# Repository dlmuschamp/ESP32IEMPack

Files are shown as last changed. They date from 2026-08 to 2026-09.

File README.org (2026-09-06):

* ESP32 Wireless IEM Pack

A first-pass wireless in-ear monitor (IEM) system: one ESP32 transmitter pack
and one ESP32 receiver pack (with support for up to 7 receiver packs).

- *RX path:* ESP-NOW -> ESP32 -> I2S -> PCM5102 DAC -> dual-gang volume pot ->
  MAX97220A headphone amp -> 3.5 mm jack
- *TX path:* TRS line-in -> PCM1808 ADC -> ESP32 I2S -> ESP-NOW to paired RX

*v1.0 boards are routed and quoted for fab* (JLCPCB Gerbers / BOM / CPL under
each =jlcpcb/production_files/=). Silk / cosmetic artwork may still change;
electrical intent for this spin is frozen. There is *no display on this version*
(a screen is a later idea, not this revision).

** First project --- how this happened

This is my first self-guided embedded systems project. Before late July 2026 I
had not written C for firmware, had not used ESP-IDF / FreeRTOS, had not read
audio or RF datasheets for a real build, and had never opened KiCad or laid out
a PCB. Pretty much everything that led to these boards was learned on the spot.

I started on a *breadboard with breakout boards* --- ESP32 modules, PCM5102,
amp, mess of jumpers --- without knowing if any of it would work. After a lot
of trial and error (wrong I2S slot formats, muted DAC, power noise, ESP-NOW
quirks), the breadboard path played audio. That proof is what made transferring
the design into KiCad worth doing.

The notes and "common mistakes" section below are the scars from that process.

Capacitor *types* to buy (ceramic vs polarized) by schematic location:
=docs/capacitor_bom.org=. PCM5102 on the RX is *PLL mode* (=SCK= to GND) with
I2S data from the ESP --- see that file.

** Timeline (repo + calendar)

| When | What |
|------+------|
| *2026-07-29* | Repo =init= (GitHub created ~2026-07-30) |
| *~2026-07-31* | Breadboard bring-up in earnest (starter code, then square-wave / DAC path) |
| *2026-08-01* | Working 440 Hz I2S tone; Philips slot fix for unmuted DAC |
| *2026-08-04 -- 08* | RX hierarchical schematics; ERC; RX schematic v1.0.0 |
| *2026-08-15* | TX audio path work (PCM1808 / 32-bit I2S slots) |
| *2026-08-30* | RX PCB layout complete; JLCPCB parts mapped; first production export |
| *2026-08-31* | RX schematics finished for v1; TX schematic draft committed |
| *2026-09-01 -- 02* | TX PCB layout + shared-part LCSC alignment; both boards ready to order |

From first commit to order-ready boards is about *five weeks* (~35 calendar
days: 2026-07-29 -> 2026-09-02). Git history on =main= has *42 commits* across
*16 days with commits*. Clustering those commit timestamps (sessions split when
gaps exceed ~3 h) gives a *lower bound on the order of ~30 hours* of
repo-visible work --- that undercounts dead ends, breadboard evenings without a
commit, and KiCad sessions that never landed in git. Real wall-clock time is
higher.

This ran in parallel with *Arbor Live* ops work at roughly *10--15 hours per
week* (~50--75 hours across the same five weeks). The IEM pack was nights and
leftover bandwidth, not a full-time build.

** Firmware

All application code is *C*. It runs on *FreeRTOS* under *ESP-IDF*, using the
related Espressif libraries (ESP-NOW / Wi-Fi, I2S, ADC, LEDC, NVS). There is
*no hardware abstraction layer* --- the firmware calls ESP-IDF APIs directly.

- =main/tx.c= :: Transmitter. Done for this version (ESP-NOW, ADC pot,
  audio packet path).
- =main/rx.c= :: Receiver entry.  Also mainly done. Use =IEM_NODE=RX= when
  you flash it.
- =main/square_wave_test.c= :: Bench I2S tone used to prove the DAC path.
- =main/rig_shared.h= :: Shared packet and state types for TX and RX.

A packet sniffer / monitor node was an early idea. It is *not* part of this
version. It could come back later as a future extension (=IEM_NODE=MON= is a
leftover hook in =main/CMakeLists.txt=). Do not treat =sniffer.c= as shipping
firmware.

How to flash the firmware onto the TX and RX packs:

#+BEGIN_SRC bash
IEM_NODE=TX idf.py fullclean flash
IEM_NODE=RX idf.py fullclean flash
#+END_SRC

=main/CMakeLists.txt= refuses to build if =IEM_NODE= is missing. That is
intentional so you do not flash the wrong image.

May need to build ESP's libraries in the project root directory first:
#+BEGIN_SRC bash
cd ESP32IEM_Pack
get_idf
#+END_SRC

** Firmware design philosophy

I did not start with a fixed architecture diagram. The philosophy below is what
*emerged* once the breadboard proved audio could move, and once ESP-NOW + I2S
constraints became real. Almost every choice in =main/tx.c=, =main/rx.c=, and
=main/rig_shared.h= is intentional --- latency, robustness, and keeping the
Wi-Fi task thin.

*** Explicit state machines (not a pile of flags)

TX and RX each run a small mode enum driven from =app_main= (=TX_MODE_*= /
=RX_MODE_*=): boot → idle/pairing → transmit/playback, with helpers like
=run_idling_state= / =run_transmitting_state= / =run_audio_playback_state=.

Why: pairing, link loss, and audio streaming are different contracts. A state
machine makes illegal transitions obvious (e.g. do not enqueue audio while still
advertising), keeps =recv_cb= from becoming a second control plane, and matches
how I already think about systems --- events in, one current mode out. Soft
reconnect (audio-sized frames from a known TX while still pairing) is a
*deliberate* exception with a named path (=try_soft_reconnect_from_audio=), not
an accidental fall-through.

*** Packet *size* is the type tag

On the wire there is no separate "opcode" header for the common path. Handlers
branch on =data_size=:

- pairing request ≈ =sizeof(pairing_req_packet_t)= (alias string)
- pairing ACK/NACK = 1 byte (=PAIR_ACK_LEN=; legacy =sizeof(pair_state_t)= also
  accepted on RX)
- audio = =sizeof(audio_packet_t)= (240 interleaved =int16= samples → 480 B)

Why: ESP-NOW already gives you length. Another type byte would cost payload
budget and another branch on every ~2.5 ms audio frame. Distinct struct sizes
make the hot path a few integer compares. Wrong-sized frames are ignored (with
rate-limited logs while pairing so a TX audio flood cannot spam the console at
~400 Hz).

*** Low overhead on the audio path (bitwise / packing / queues of pointers)

Audio is the budget that matters. Design choices that keep CPU and copies down:

- *Pack once.* I2S often delivers 32-bit slot words; TX shifts with =>>= 16= into
  =int16= PCM for the air format (PCM1808 / slot width forced this; the shift is
  the cheap conversion, not a float path).
- *Low-latency packets (this branch).* 240 samples @ 48 kHz = 2.5 ms/packet,
  ~400 pkt/s --- aggressive vs the old 7.5 ms / ~133 pkt/s breadboard-stable
  choice. Relies on =send_cb= pacing + RX pointer-pool. If ESP-NOW drops climb,
  step toward 288 samples (3 ms) before abandoning the ~10 ms e2e target.
- *Pointer-pool jitter buffer on RX.* Queues carry =audio_packet_t *= into a
  fixed pool, not full packet copies on every hop; playback pins to another core
  with a short pre-buffer (2 packets / 5 ms) so the first I2S write does not
  underrun. PCM5102: close =SW2= (FLT=IIR) for ~0.4 ms less DAC filter delay.
- *Keep heavy work off Wi-Fi callbacks.* Pairing work is queued to the state
  machine; =esp_now_add_peer= and I2S enable happen in safe contexts. Send
  pacing waits for =send_cb= so bursts do not disorder callbacks / =NO_MEM=.
- *Silence is zeros, not a skipped send* while transmitting, so the RX timeout
  logic sees a live link instead of a mysterious gap.

None of this was "optimize everything." It was: find the hot path, make the
common case boring and cheap, and put complexity in pairing / reconnect where
milliseconds matter less than correctness.

*** What I refused to do (for v1)

- No HAL wrapping ESP-IDF --- I wanted to learn the real APIs.
- No sniffer/monitor node in the shipping image (hook left in CMake only).
- No display firmware on this revision.
- Unencrypted ESP-NOW for now (explicit TODO, not forgotten security theater).

*** Files to read

- =main/rig_shared.h= --- packet structs, sample counts, ESP-NOW v2 gate
- =main/tx.c= --- TX modes, size-filtered pairing recv, I2S → pack → send
- =main/rx.c= --- RX modes, size-based dispatch, soft join, pointer-pool playback

** What this version is (and is not)

| Topic    | This version (v1.0 order spin)                   | Not this version                         |
|----------+--------------------------------------------------+------------------------------------------|
| Display  | None                                             | A screen or later UI                     |
| RX power | USB-C from a 10,000 mAh 5 V bank -> LM3940 3.3 V | TP4056 + 2000 mAh LiPo/3xAA (Deprecated) |
| TX power | The same kind of 10,000 mAh 5 V bank as the RX   | A different chemistry or one shared bank |
| Radio    | ESP32-WROOM-32U/UE + =ANT1= 2.4 GHz U.FL pigtail | On-module PCB antenna (32E / 32D)        |
| RX audio | I2S -> PCM5102 -> pot -> MAX97220A -> jack       | I2C audio (DAC/ADC here are I2S)         |
| TX audio | TRS -> PCM1808 ADC -> I2S -> ESP-NOW             | Shared ADC/DAC IC across TX and RX       |
| Firmware | C + FreeRTOS + ESP-IDF                           | A HAL, or a sniffer / monitor node       |
| PCB      | RX + TX routed, DRC-clean enough to fab          | Final silk art / v2 mechanical polish    |

TX and RX each get their *own* identical 10,000 mAh bank. Do not power both
packs from one bank if you want them to roam independently.

** Repo map

#+BEGIN_SRC
main/                  ESP-IDF C firmware (FreeRTOS)
  rig_shared.h         Shared packet / state types (TX and RX)
  tx.c                 Transmitter --- done for this version
  rx.c                 Receiver entry
  square_wave_test.c   Bench I2S tone for the DAC path
KiCad/RX_SKETCHES/     RX v1 schematic + routed PCB + jlcpcb/ exports
KiCad/TX_SKETCHES/     TX v1 schematic + routed PCB + jlcpcb/ exports
KiCad/Custom_Part_Downloads/  SnapEDA / custom symbols and footprints
docs/                  Cap BOM, hardware revisions, price notes, bench notes
#+END_SRC

Production uploads (Gerber zip + BOM + CPL):

- =KiCad/RX_SKETCHES/jlcpcb/production_files/=
- =KiCad/TX_SKETCHES/jlcpcb/production_files/=

Hand-fit / not on the fab BOM: ESP32 modules (=U2=), =ANT1= U.FL pigtails
(both boards), RX dual-gang pot =VR1= (=PTN09S2-H10120K1A= --- DigiKey/Mouser;
not on LCSC).

** Hardware (RX 1.0 KiCad)

Hierarchical sheets, in signal order:

1. =pwr_mgmt= --- USB-C (CC pulldowns), CP2102C UART bridge, LM3940 5 V -> 3.3 V
2. =esp_rx= --- ESP32-WROOM-32U + =ANT1= (U.FL pigtail / 2.4 GHz antenna)
3. =dac= --- PCM5102
4. =vol_ctrl= --- dual-gang log pot + 0% switch
5. =amp= --- MAX97220A to the 3.5 mm jack

** Hardware (TX 1.0 KiCad)

1. =pwr_mgmt= --- same USB-C / CP2102C / LM3940 pattern as RX
2. =esp_tx= --- ESP32-WROOM-32U + =ANT1=
3. =adc= --- PCM1808 (I2S slave; MD0/MD1/FMT strapped low) + TRS line-in

*** Firmware I2S map (do not change these GPIOs)

RX contract is =main/rx.c= on branch =main= (=DOUT_PIN 25=). TX uses
=DIN_PIN 35= on the *transmitter* board only.

| Hierarchical label | ESP32 GPIO | Firmware name                                      |
|--------------------+------------+----------------------------------------------------|
| =BCK=              | IO33       | =BCK_PIN=                                          |
| =LRCLK=            | IO32       | =LRCK_PIN=                                         |
| =DOUT=             | IO25       | =DOUT_PIN= (ESP *out* -> PCM5102 pin *DIN*)        |

Hardware change log (what / why / evidence): =docs/hardware_revisions.org=.

UART programming: =TXD= = TXD0/IO1, =RXD= = RXD0/IO3. Auto-program straps:
=ESP_EN= = EN, =ESP_IO0= = IO0.

*** Antenna (=ANT1= on =esp_rx=)

The *32U* module has a U.FL connector and *no PCB antenna*. =ANT1= is a BOM /
documentation part: a *2.4 GHz, 50 ohm antenna on a U.FL / IPEX pigtail* that
mates to the connector already on the module. It is not wired to a GPIO. It has
no PCB footprint --- you buy the pigtail, you do not etch an antenna.

*** Analog (PCM5102 datasheet vs experiments)

The PCM5102 datasheet analog network for a ~10 kOhm load is already on the DAC
sheet (=R16=/=R17= 470 ohm, =C20=/=C21= 2.2 nF):

=OUTL/OUTR -> 470 ohm series -> =DAC_OUT=, with *2.2 nF from that node to GND*.

That ~10 kOhm load is mainly the *dual-gang pot* (10 kOhm), which sits right after
=DAC_OUT=. Keep the pot; leave the 470 ohm + 2.2 nF alone unless you change that
load a lot.

MAX97220*A* (and B/E) has *no* fixed Zin --- input resistance is your external
=RIN= (=AV = -RF/RIN=; RF typically 4.7 kOhm--100 kOhm). =RIN= is now *47 kOhm*
and =RF= is *4.7 kOhm*, and all eight parts are *populated* (no longer DNP).
Changing =RF= does *not* require retuning the DAC RC. See
[[*Volume, gain, and audible-band response][Volume, gain, and audible-band response]]
for why those values, and for the loudness math.
MAX97220*C*/*D* are *fixed +6 dB* (internal Rs); wrong if you want resistor-set
max loudness.

The experimental 1 kOhm / 10 ohm pad on =vol_ctrl= is *DNP*, with a short across
the 1 kOhm positions so an empty series part does not open the audio path. You
do *not* need that pad for level safety --- filtered =DAC_OUT= can feed the pot
directly (see =docs/hardware_revisions.org=).

*** Volume, gain, and audible-band response

All numbers here are reproduced on the schematic itself: the gain budget is on
the =amp= sheet, the filter audit is on the =dac= sheet.

**** Gain budget

Two resistor groups set the gain, and each group must stay internally matched or
the pseudo-differential balance (CMRR) is lost:

| Group  | Parts             | Value  | Role             |
|--------+-------------------+--------+------------------|
| =RF=   | R1, R3, R9, R10   | 4.7 k  | gain numerator   |
| =RIN=  | R2, R4, R5, R6    | 47 k   | gain denominator |

R1/R10 are the feedback resistors, R3/R9 are the matching shunts on the =IN+=
legs. R4/R2 are the input series resistors, R5/R6 their matching partners.

| Stage                              | Expression       |     dB |
|------------------------------------+------------------+--------|
| =R16=/=R17= + =VR1= divider        | 10k / (470 + 10k) |  -0.40 |
| Amp gain =RF/RIN=                  | 4.7k / 47k        | -20.00 |
| *Total*                            |                   | *-20.40* (x0.0955) |

The PCM5102A puts out *2.1 Vrms* at full scale, so with =VR1= wide open:

: Vout = 2.1 x 0.0955 = 0.201 Vrms at J1

**** Why 47 k and not the datasheet's 10 k

The 10 kOhm in the typical application circuit is a generic reference, not a
design for a 2.1 Vrms source driving sensitive IEMs. Raising =RIN= fixes three
things at once, and raising the pot value instead would only fix the second:

1. *Gain.* Unity gain hands the DAC's full 2.1 Vrms straight to the IEM.
2. *Pot taper.* A 10 kOhm =RIN= loads a 10 kOhm pot 1:1, which squashes the taper
   and makes the top of the range behave badly. 47 k gives a 4.7x ratio.
3. *Bass rolloff.* The coupling caps work against =RIN=, not against the pot. At
   10 k the corner sat at *33.9 Hz*, costing *-5.87 dB at 20 Hz*. At 47 k with
   the 1 uF caps it is 3.4 Hz.

Do *not* also fit a larger pot. 47 k =RIN= with a 50 k pot puts the loading ratio
back at ~1:1 and undoes point 2.

**** Loudness math

: Peak SPL = IEM sensitivity (dB/Vrms) + 20 x log10(Vout)

Manufacturers quote sensitivity two different ways. If yours is in *dB/mW* you
must convert to *dB/Vrms* first, using the headphone impedance Z in ohms:

: dB/Vrms = dB/mW + 10 x log10(1000 / Z)

That falls out of =P = V^2/Z=. One volt into Z ohms delivers =1000/Z= milliwatts,
and converting a power ratio to dB is =10 x log10=. At Z = 1000 ohms the two
figures are identical; below that dB/Vrms is the larger number.

| IEM               | Spec               |     Z | dB/Vrms | Peak SPL at max volume |
|-------------------+--------------------+-------+---------+------------------------|
| KZ ZS10 Pro X     | 112 dB (as dB/mW)  | 29 R  |   127.4 | 113.4 dB               |
| KZ, +3 dB tol.    | 115 dB/mW          | 29 R  |   130.4 | 116.4 dB               |
| Moondrop Aria     | 122 dB/Vrms        | 32 R  |   122.0 | 108.0 dB               |

*Caveat worth checking yourself:* KZ publishes "112±3dB" without stating the
reference. Treating it as dB/mW is the conservative reading (it makes the IEM
127 dB/Vrms, i.e. louder). If it is actually already dB/Vrms, max volume is a
much tamer 98 dB. Moondrop's figure is unambiguous --- they state dB/Vrms.

**** Sources

- Conversion formula, =dB(V) = dB(mW) - 10 x log10(Z/1000)=:
  [[https://en.wikipedia.org/wiki/Headphones#Sensitivity][Wikipedia, Headphones -- Sensitivity]]
- Same formula with a worked example and a calculator:
  [[https://audiocalcs.uk/headphones-and-iem/headphone-sensitivity-calculator/][AudioCalcs, Headphone Sensitivity Calculator]] and
  [[https://www.omnicalculator.com/everyday-life/headphone-power][Omni Calculator, Headphone Power]]
- Full algebraic derivation from =P = V^2/R=:
  [[https://www.head-fi.org/threads/db-per-milliwhat-efficiency-vs-sensitivity-vs-how-loud-do-they-really-go.168037/][Head-Fi, "dB per milliWHAT?"]]
- Moondrop Aria, 122 dB/Vrms @ 1 kHz, 32 R ±15%:
  [[https://moondroplab.com/en/products/aria][MOONDROP official product page]]
- KZ ZS10 Pro X, 29 R, 112±3 dB:
  [[https://www.linsoul.com/products/kz-zs10-pro-x][Linsoul product page]]
- PCM5102A full-scale output (2.1 Vrms) and mode-pin behaviour: TI PCM510xA
  datasheet. MAX97220 gain =AV = -RF/RIN=: Analog Devices/Maxim MAX9722x datasheet.

Manufacturer sensitivity specs are frequently optimistic. If you want to be
rigorous, use third-party measurements for the IEM you actually care about and
re-run the formula above.

**** Filter audit

Only *two* reactive components sit in the audio path. Everything else in the
chain is resistive, and because the MAX97220 uses a ground-referenced
DirectDrive output, =J1= needs no output coupling cap and has none --- so there
is no output pole at all.

| # | Network                                | Type            | Corner   | Error in band     |
|---+----------------------------------------+-----------------+----------+-------------------|
| 1 | =R16=/=R17= 470 R with =C20=/=C21= 2.2 nF | reconstruction  | 161 kHz  | -0.07 dB @ 20 kHz |
| 2 | =C1=/=C4= 1 uF into =RIN= 47 k         | input coupling  | 3.4 Hz   | -0.12 dB @ 20 Hz  |

Network 1 is loaded by =VR1=, so the resistance setting that corner is 470 R in
parallel with the 10 kOhm pot, which is 449 R:
=fc = 1 / (2 x pi x 449 x 2.2n) = 161 kHz=.

Network 2 sees =RIN= directly, because the inverting input is a virtual ground:
=fc = 1 / (2 x pi x 47k x 1u) = 3.4 Hz=.

=C2=/=C3= form the matching leg on the =IN+= inputs. They carry no signal, so
they set noise and CMRR rather than frequency response. They are *1 uF as well*:
the two halves of each pseudo-differential pair have to track at low frequencies
or CMRR degrades down there, so all four caps must be changed together.

Resulting deviation across the audible band:

| Frequency | Deviation |
|-----------+-----------|
| 20 Hz     | -0.12 dB  |
| 30 Hz     | -0.06 dB  |
| 50 Hz     | -0.02 dB  |
| 100 Hz    |  0.00 dB  |
| 1 kHz     |  0.00 dB  |
| 10 kHz    | -0.02 dB  |
| 20 kHz    | -0.07 dB  |

For comparison, the old 10 k =RIN= gave -5.87 dB at 20 Hz and -3.56 dB at 30 Hz,
and 47 k with the original 0.47 uF caps gave -0.53 dB at 20 Hz.

**** Why 1 uF and not 0.47 uF

Flatness is the smaller half of the reason. The bigger one is distortion: Class
II ceramics (X7R and friends) are nonlinear, and the distortion they contribute
scales with the signal voltage developed *across* the cap. A coupling cap only
develops appreciable voltage near its corner, so the low end is exactly where a
ceramic misbehaves.

| C_in    | Xc @ 20 Hz | Signal across cap @ 20 Hz | @ 50 Hz | Corner  |
|---------+------------+---------------------------+---------+---------|
| 0.47 uF | 16.9 kOhm  | 33.9%                     | 14.3%   | 7.20 Hz |
| 1 uF    | 8.0 kOhm   | 16.7%                     | 6.8%    | 3.39 Hz |
| 2.2 uF  | 3.6 kOhm   | 7.7%                      | 3.1%    | 1.54 Hz |

At 0.47 uF a third of the 20 Hz signal sat across the dielectric. 1 uF halves
that. 2.2 uF would halve it again, but a 1.54 Hz corner passes more subsonic
rumble and DC drift into the amp for +0.09 dB of flatness, so 1 uF is the stop
point --- conventional practice puts a coupling corner around 3--5 Hz.

All four are the same =C_0805_2012Metric_Pad1.18x1.45mm_HandSolder= footprint as
before, so this is a value-only change with no layout impact. Specify *X7R or
better* and avoid Y5V/Z5U, whose capacitance collapses with temperature and bias
and would move the corner around unpredictably.

**** Changing the gain later

Raise =RF= (R1, R3, R9, R10) together and leave =RIN= alone:

| =RF=  | Gain      | Vout      | KZ ZS10 Pro X | Moondrop Aria |
|-------+-----------+-----------+---------------+---------------|
| 4.7 k | -20.4 dB  | 0.201 Vrms | 113.4 dB     | 108.0 dB      |
| 10 k  | -13.8 dB  | 0.427 Vrms | 120.0 dB     | 114.6 dB      |

Do not go past 10 k. Risk of hearing damage climbs steeply above ~120 dB SPL.
Since all eight resistors share one 0805 hand-solder footprint, gain is chosen at
build time --- there is no need for spare DNP trim positions on the board.

*** Hand assembly

Every schematic resistor and capacitor now uses the KiCad *0805 hand-solder*
footprint (longer pads):

- =Resistor_SMD:R_0805_2012Metric_Pad1.20x1.40mm_HandSolder=
- =Capacitor_SMD:C_0805_2012Metric_Pad1.15x1.40mm_HandSolder=

Buy 0805 parts. ICs, the USB-C jack, the 3.5 mm jack, the pot, SOT-23
transistors, and the WROOM module *cannot* become 0805 --- those packages are
the part. TQFN / WQFN still need a hot plate, hot air, or a board house.

The =.kicad_pcb= footprint *names* were renamed, but the copper pads are still
the old 0201 geometry until you *Update PCB from Schematic* in KiCad.

*** Datasheet audit (what was wrong, what we changed)

Checked against the PCM5102 / PCM5102A, MAX97220A, LM3940, CP2102C, and
ESP32-WROOM-32U hardware notes.

| Issue | Spec | Fix on this branch |
|-------+------+--------------------|
| DAC 470R+2.2nF on =LDOO= / not on =OUTL=/=OUTR= | Filter belongs on pins 6/7. =LDOO= pin 18 needs 0.1 uF to GND | Rewired =R16=/=R17= to =OUTL=/=OUTR=. Added =C28= 0.1 uF on =LDOO= |
| Flying cap 2.54 mm off =CAPP=/=CAPM= pin ends | 2.2 uF between pins 2 and 4 | Extra wires to the actual pin ends |
| Headphone jack on =PVSS=/=SVSS= | Those are the -V charge-pump / BIAS rails. Audio is =OUTL=/=OUTR=. Sleeve is GND | Tip==OUTL=, Ring==OUTR=, Sleeve=GND. =C29= 1 uF =PVSS= to GND. =SVSS= tied to =PVSS= |
| CP2102C =VIO= left off =VDD= | =VIO= = I/O rail, same 3.3 V as the ESP | Wire =VIO= to =VDD=. =R29= 1 k pulls =~{RST}= to =VIO= |
| LM3940 missing 0.47 uF Cin | Datasheet: 0.47 uF on IN, 33 uF low-ESR on OUT | Added =C31= 0.47 uF. Keep =C23= 33 uF; if it is ceramic, ESR can be *too low* --- prefer tantalum or add ~0.5 ohm |
| ESP =IO0= with no pull-up | Strap should sit high for normal boot | =R30= 10 k to +3V3 |
| =D1= VBUS clamp on the *switched* +5V rail | An ESD clamp has to sit on the pin that is actually exposed to a finger | Moved =D1= pin 2 to the connector-side rail, now named =VBUS_RAW= (=J6= VBUS + =SW4= input) |

**** Why =D1= moved to the unswitched side

=D1= is an =SP0503BAHT=, a four-line TVS array: one common anode on GND and three
independent cathodes. Two of those cathodes clamp =D+= and =D-= and did not move.
The third was clamping =+5V=, which is the rail *after* =SW4=.

The point of a TVS is to shunt a static discharge to ground before it reaches
anything fragile. The place a discharge actually enters this board is the USB-C
connector, because that is the only conductor a person can touch. With the clamp
behind the power switch, flipping =SW4= to OFF disconnects the clamp from the
connector and leaves =J6='s VBUS pin unprotected --- so the board is *least*
protected in the state where it is most likely to be handled, unplugged, and
tossed in a bag. Moving the clamp to =VBUS_RAW= puts it on the exposed pin
permanently.

This does *not* compromise the off state you asked for. A TVS is an open circuit
below its standoff voltage; it conducts only during a transient. =SW4= still
breaks the rail feeding =U4=, =U5=, and everything downstream, so OFF is still
genuinely dead --- the only thing now sitting on the connector side is a diode
that draws leakage in the nanoamp range.

Still true / do not "fix" into something else:

- I2S GPIOs stay IO33 / IO32 / IO25 (breadboard + =square_wave_test.c=).
- USB-C =Rd= 5.1 k on CC1/CC2 is correct for a UFP / power-bank sink.
- CP2102C =R25= 22.1 k / =R26= 47.5 k is the *VBUS* divider, not a =VIO= divider.
- Amp gain resistors are *populated*, not DNP. An unpopulated =RF= leaves the
  MAX97220 with no feedback path, so it runs open loop and slams to the rails ---
  that is louder and less safe than a wrong gain, not quieter.
- LM3940 in SOT-223 will get hot at 5 V -> 3.3 V under ESP TX + amp load --- copper pour / thermal vias at layout time.

** Current status (2026-09-02)

- [X] Breadboard RX path plays (ESP32 I2S -> PCM5102 -> amp -> IEMs)
- [X] =tx.c= / =rx.c= firmware for this version
- [X] Repo + KiCad folder split (=RX_SKETCHES= / =TX_SKETCHES=)
- [X] RX + TX hierarchical schematics; shared =pwr_mgmt= / ESP patterns
- [X] Passives on 0805 HandSolder footprints; LCSC mapped for JLCPCB
- [X] RX PCB routed; TX PCB routed; Edge.Cuts ~90.5 x 55.25 mm (Altoids-ish)
- [X] Gerbers + BOM + CPL exported for both boards
- [ ] Order bare PCBs + LCSC parts; combine shipment
- [ ] Buy / fit ESP modules, U.FL pigtails, RX =VR1= pot; hand assembly / bring-up
- [ ] Confirm ESP-NOW range and audio on fabricated boards
- [ ] Optional: silk / logo artwork respin (non-functional)

No display work on this revision. No sniffer / monitor node on this revision.

** My first-board mistakes

 The list below is the stuff that I already made mistakes on. Listed so I can check it every time
 I move a part or add a hierarchical label.

*** 1. Rotating a symbol does not remap pin numbers

Pin 3 is still =EN= after a 270 degree rotate. KiCad only rotates the *drawing*
and the *sheet coordinates* of the pins around the symbol origin. Hierarchical
labels and wires that stay put will attach to whichever pin rotated into that
spot.

After any rotate: click each pin, read the name, then move the label onto
*that* pin. Do not assume "left side is still EN."

*** 2. Hierarchical labels connect through wires, not vibes

A label sitting near a pin is not connected. ERC and the ratsnest follow
*wires and pin ends*. After a rotate, a label can look "on" the chip and still
sit on empty space or on the wrong pin (=ESP_IO0= on =EN=, =BCK= on =DEMP=,
=SHDN_SIGNAL= on =C1N=).

Triple-check every hierarchical label against the *pin name*, not the side of
the box.

*** 3. Same-ish names are different pins

| You meant                         | Easy to hit instead      | What happens                              |
|-----------------------------------+--------------------------+-------------------------------------------|
| PCM5102 =BCK= / =DIN= / =LRCK=    | =DEMP= / =XSMT= / =FMT=  | DAC never gets PCM; clocks toggle config  |
| PCM5102 =OUTL= / =OUTR=           | =LDOO= / =VNEG=          | Analog filter on the 1.8 V LDO pin        |
| MAX97220 =~{SHDN}=                | =C1N= (charge-pump cap)  | Volume switch does not mute; VSS breaks   |
| MAX97220 =OUTL= / =OUTR=          | =PVSS= / =SVSS= (BIAS)   | Jack sits on the charge-pump rail         |
| ESP =TXD0= / =RXD0=               | =SENSOR_VN= / empty      | USB-C UART programming dies               |
| I2S                               | I2C                      | Wrong bus, wrong pins, wrong mental model |

Read the pin *name* in the status bar before you drop the label.

*** 4. Firmware GPIO numbers are the contract

=#define BCK_PIN 33= is IO33 on the module, period. Do not "clean up" the
schematic onto IO18/19/23 unless you change the C defines too. Label =DIN= on
the DAC is the ESP's *DOUT*.

*** 5. The footprint field is a part you have to buy and solder

If the field says =R_0201_0603Metric=, you will get 0201s. Bulk 10 uF parts
basically do not exist in 0201, and you will not hand-assemble them. For a
hand-built proto use the =*_HandSolder= 0805 footprint (longer iron pads), then
*Update PCB from Schematic* so the copper matches.

*** 6. DNP does not delete the net

KiCad "Do not populate" still leaves the schematic wires. If you DNP a *series*
resistor, the path goes open unless you add a solder-bridge / short. If you DNP
a *shunt*, leaving the pads empty is correct (no short to GND).

*** 7. 32U vs 32E, A vs D, datasheet vs doodle

- *32U* = U.FL only. *32E/32D* = PCB antenna. Pick one and BOM the matching RF
  parts.
- *MAX97220A/B/E* = external gain (=RF/RIN=). *C/D* = fixed +6 dB. Letter matters.
- Prefer the datasheet application circuit (470 ohm + 2.2 nF here) over a pad
  you tried on the bench, unless you measured why the pad is better.

*** 9. Power and analog will buzz on a breadboard

Long jumpers, no ground plane, and an ESP32 radio next to a DAC is a buzz/hiss
machine. That does not automatically mean the circuit is wrong. A PCB with
short I2S, local decoupling, and a solid GND will almost certainly be quieter.
It is not guaranteed to be silent on the first spin.

** Author

Damian Luciano Muschamp

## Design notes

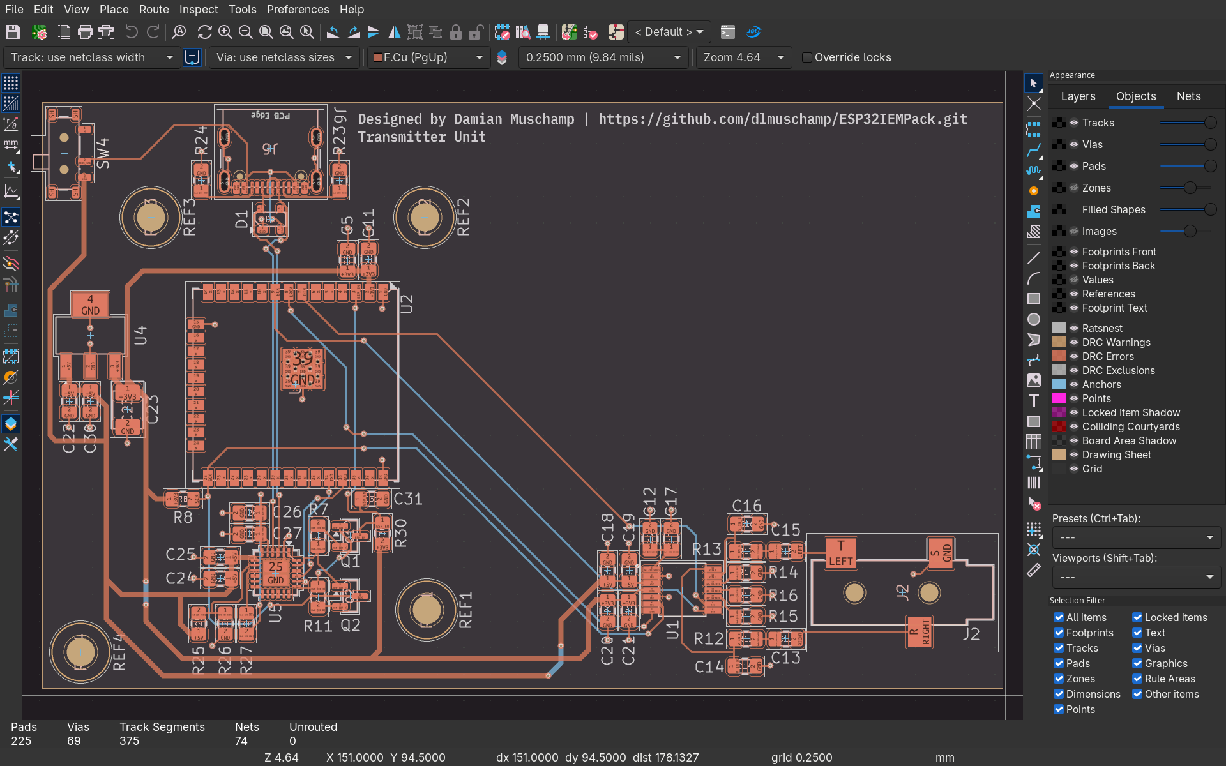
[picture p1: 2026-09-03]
KiCad/TX_SKETCHES/Gallery/TX_PCB.png

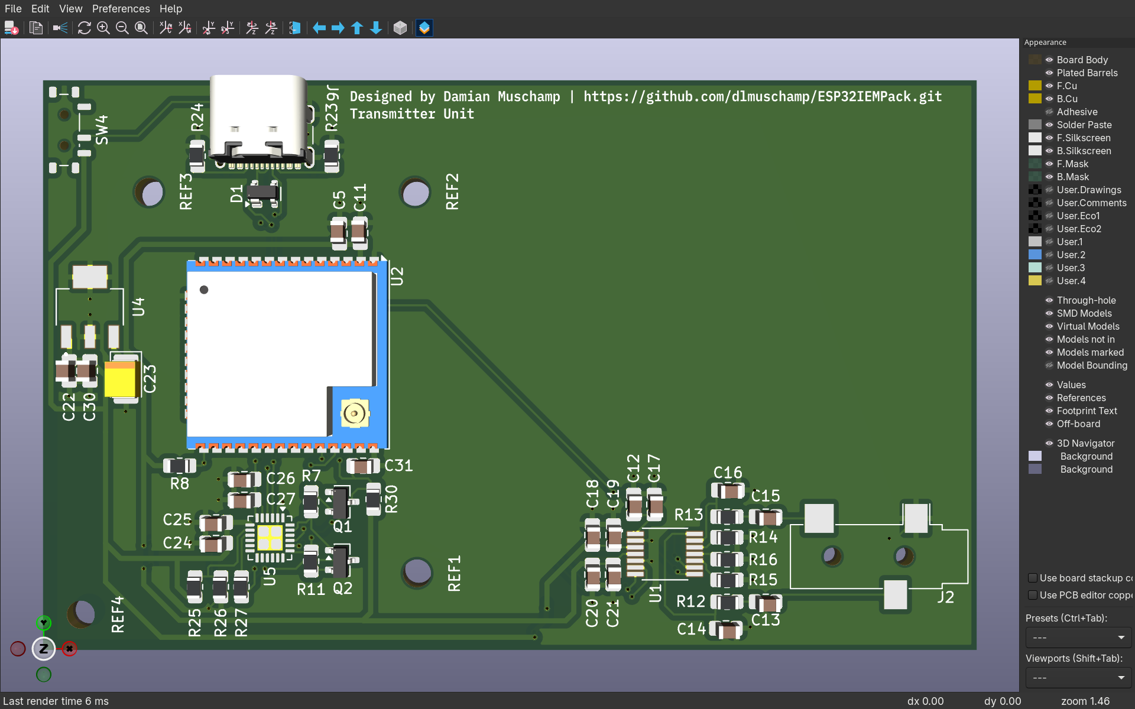
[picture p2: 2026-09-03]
KiCad/TX_SKETCHES/Gallery/TX_PCB_3D.png

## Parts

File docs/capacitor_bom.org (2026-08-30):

#+TITLE: RX capacitor buy list (type by location)
#+AUTHOR: Damian Luciano Muschamp
#+OPTIONS: toc:2 num:nil

* Purpose

What *type* of capacitor to buy for each RX schematic location --- ceramic vs
polarized --- so the BOM matches the datasheets. Values match
=KiCad/RX_SKETCHES/= as of 2026-08-25; re-check refs if you renumber parts.

Package default for hand-built boards: *0805* (or the HandSolder footprints
already on the symbols). Voltage rating: use *≥6.3 V* on 3.3 V rails; *≥10 V*
is safer. Prefer *X7R* (or X5R) for ceramics unless noted.

* Quick rule

| Use | Type |
|-----+------|
| Charge-pump flying / hold caps | *Always ceramic* (never electrolytic) |
| HF bypass next to IC pins (0.1 uF) | *Ceramic* |
| Input coupling / small filters | *Ceramic* |
| Large bulk on 3.3 V where a =+= is drawn | *Polarized OK* (tantalum / electrolytic) *or* ceramic MLCC |
| LM3940 =OUT= 33 uF | *Tantalum (or Al + tant)* with ESR in the LM3940 band --- not a random ultra-low-ESR ceramic |

* DAC sheet (=dac=) --- PCM5102

| Ref | Value | Buy | Why / where |
|-----+-------+-----+-------------|
| =C12= | 10 uF | *Polarized* (=Device:C_Polarized= on sheet) *or* 10 uF ceramic | Bulk on DVDD/AVDD/CPVDD to GND. =+= to *+3V3* if polarized. |
| =C13=, =C16=, =C17=, =C19= | 0.1 uF | *Ceramic* | Local HF bypass (supplies / LDOO). |
| =C14= | 2.2 uF | *Ceramic* | CAPP--CAPM flying cap. *Not* polarized. |
| =C15= | 2.2 uF | *Ceramic* | VNEG to GND (VNEG is *-3.3 V*). *Not* polarized. |
| =C20=, =C21= | 2.2 nF | *Ceramic* (C0G/NP0 nice, X7R OK) | Analog out filter shunt after 470 R on =OUTL=/=OUTR=. |

Do *not* put electrolytics on =C14=/=C15=. TI expects ~2.2 uF ceramics on the
charge pump; larger values can stress the pump.

* Amp sheet (=amp=) --- MAX97220A

Datasheet: low-ESR *ceramic*, X7R preferred. No polarized parts required.

| Ref | Value | Buy | Why / where |
|-----+-------+-----+-------------|
| =C7= | 1 uF | *Ceramic* | Charge-pump flying (=C1P=--=C1N=). |
| =C6= | 1 uF | *Ceramic* | Charge-pump hold / =PVSS= network. |
| =C8=, =C9= | 1 uF | *Ceramic* | =PVDD= / =SVDD= bypass to GND. |
| =C10= | 0.1 uF | *Ceramic* | Extra HF / =BIAS= path as drawn. |
| =C1=--=C4= | 0.47 uF | *Ceramic* | Input coupling (pseudo-diff). |

* Power management (=pwr_mgmt=) --- LM3940 + CP2102

| Ref | Value | Buy | Why / where |
|-----+-------+-----+-------------|
| =C23= | 33 uF | *Solid tantalum* (preferred) or Al electrolytic + small tant; watch *ESR* | LM3940 =OUT=. Minimum 33 uF; ESR must stay in the datasheet window. If polarized: =+= on *+3V3*. Consider marking =C_Polarized= on the sheet. |
| =C22= | 0.47 uF | *Ceramic* | LM3940 =IN= minimum local. |
| =C30= | 22 uF | *Ceramic* MLCC *or* polarized bulk | Extra bulk on USB / 5 V in (larger than the 0.47 uF minimum is fine). |
| =C24=, =C26= | 4.7 uF | *Ceramic* | CP2102 local bulk (VDD / bus as drawn). |
| =C25=, =C27= | 0.1 uF | *Ceramic* | CP2102 HF bypass. |

* ESP RX (=esp_rx=) --- WROOM module

| Ref | Value | Buy | Why / where |
|-----+-------+-----+-------------|
| =C5= | 22 uF | *Ceramic* MLCC (typical) | Module / 3V3 bulk. Polarized OK if you prefer; =+= to +3V3. |
| =C11=, =C31= | 0.1 uF | *Ceramic* | Local bypass (EN timing / rails as drawn). |

* Volume control (=vol_ctrl=)

No capacitors on this sheet.

* Shopping checklist (aggregated)

Buy at least:

- Ceramic 0.1 uF 0805 --- many (bypass)
- Ceramic 0.47 uF 0805 --- amp inputs + LM3940 Cin
- Ceramic 1 uF 0805 X7R --- MAX97220 charge pump + VDD bypass
- Ceramic 2.2 uF 0805 --- PCM5102 charge pump (=C14=, =C15=)
- Ceramic 2.2 nF --- DAC out filter (=C20=, =C21=)
- Ceramic 4.7 uF --- CP2102
- Ceramic or polarized 10 uF --- DAC bulk (=C12=)
- Ceramic 22 uF --- ESP / USB bulk (=C5=, =C30=)
- *Tantalum (or ESR-safe) 33 uF* --- LM3940 out (=C23=) ***do not skip ESR***

* PCM5102 clock mode (ESP RX) --- PLL vs "PCM"

These are different ideas:

1. *Audio data* --- You always send *I2S / PCM samples* from the ESP (=DOUT= ->
   DAC =DIN=, plus =BCK= / =LRCK=). Firmware is I2S master; format switch
   =FMT= low = I2S.

2. *System clock source* --- PCM5102 either:
   - *PLL mode* --- tie =SCK= to *GND*; chip makes its internal clock from
     =BCK=/=LRCK= (datasheet PLL operation).
   - *External SCK / non-PLL* --- drive a real system clock into =SCK=
     (needs an MCLK from the ESP or an oscillator).

*For this RX pack: use PLL mode* (=SCK= grounded). That matches the schematic
note and the usual ESP32 I2S master setup (BCK/LRCK/DOUT only; no MCLK pin in
=rx.c=). You are *not* choosing "PCM instead of PLL" --- you use *PLL for the
clock* and *I2S/PCM for the data*.

Refs: PCM5102 datasheet system-clock / PLL sections; ESP-IDF I2S std config
with =mclk = I2S_GPIO_UNUSED=.

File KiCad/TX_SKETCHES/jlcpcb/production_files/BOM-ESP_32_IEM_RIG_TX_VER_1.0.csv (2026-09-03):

Comment | Designator | Footprint | LCSC | Quantity
0.1u | C11,C17,C19,C21,C25,C27,C31 | C_0805_2012Metric_Pad1.18x1.45mm_HandSolder | C49678 | 7
0.47u | C22 | C_0805_2012Metric_Pad1.18x1.45mm_HandSolder | C53134 | 1
100k | R14,R15,R16 | R_0805_2012Metric_Pad1.20x1.40mm_HandSolder | C149504 | 3
10k | R11,R30,R7,R8 | R_0805_2012Metric_Pad1.20x1.40mm_HandSolder | C17414 | 4
10uF | C12,C18,C20 | C_0805_2012Metric_Pad1.18x1.45mm_HandSolder | C15850 | 3
120 | R12,R13 | R_0805_2012Metric_Pad1.20x1.40mm_HandSolder | C17437 | 2
1k | R27 | R_0805_2012Metric_Pad1.20x1.40mm_HandSolder | C17513 | 1
1nF | C14,C16 | C_0805_2012Metric_Pad1.18x1.45mm_HandSolder | C46653 | 2
1uF | C13,C15 | C_0805_2012Metric_Pad1.18x1.45mm_HandSolder | C28323 | 2
22k | R25 | R_0805_2012Metric_Pad1.20x1.40mm_HandSolder | C17560 | 1
22u | C30,C5 | C_0805_2012Metric_Pad1.18x1.45mm_HandSolder | C45783 | 2
33u | C23 | CP_EIA-3528-12_Kemet-T_HandSolder | C7202 | 1
4.7u | C24,C26 | C_0805_2012Metric_Pad1.18x1.45mm_HandSolder | C1779 | 2
47k | R26 | R_0805_2012Metric_Pad1.20x1.40mm_HandSolder | C17713 | 1
5.1k | R23,R24 | R_0805_2012Metric_Pad1.20x1.40mm_HandSolder | C27834 | 2
AudioJack3 | J2 | Jack_3.5mm_CUI_SJ-3523-SMT_Horizontal | C4991872 | 1
CP2102C-Axx-xQFN24 | U5 | WQFN-24-1EP_4x4mm_P0.5mm_EP2.45x2.45mm | C43119339 | 1
LM3940IMPX-3.3_NOPB | U4 | SOT230P700X180-4N | C544820 | 1
ON/OFF | SW4 | SW_SPDT_Shouhan_MSK12C02 | C431540 | 1
PCM1808PWG4 | U1 | SOP65P640X120-14N | C55513 | 1
S8050 | Q1,Q2 | SOT-23 | C2146 | 2
SP0503BAHT | D1 | SOT-143 | C7074 | 1
USB_C_Receptacle_USB2.0_16P | J6 | USB_C_Receptacle_GCT_USB4105-xx-A_16P_TopMnt_Horizontal | C5337088 | 1

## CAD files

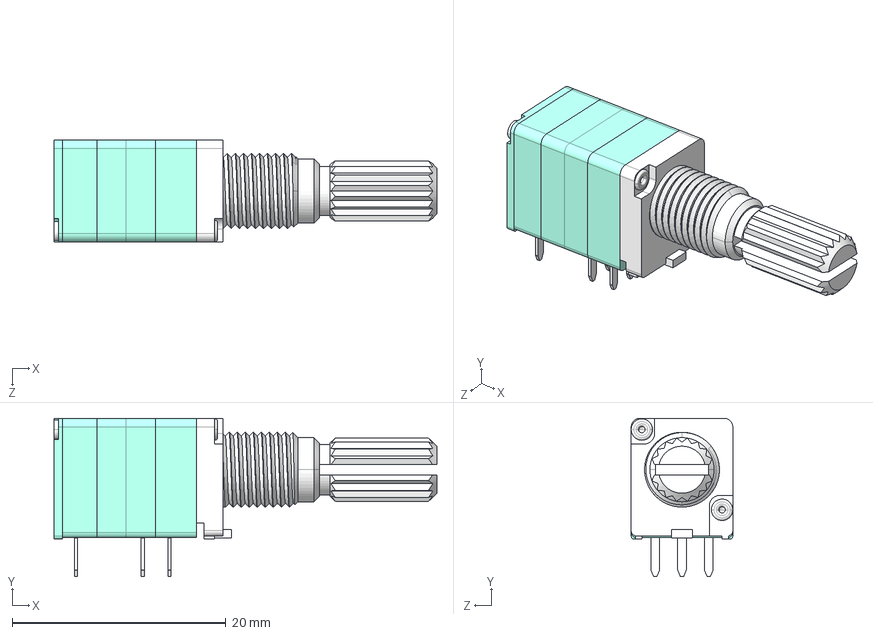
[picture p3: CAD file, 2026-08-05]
KiCad/Custom_Part_Downloads/LIB_PTN09S2-H10120K1A/PTN09S2-H10120K1A/3D/PTN09S2-H10120K1A.stp
35.8 x 14.8 x 9.50 mm
FIX_PLATE
PTN09S2-H
BUSHING-7S
K_SHAFT_L20

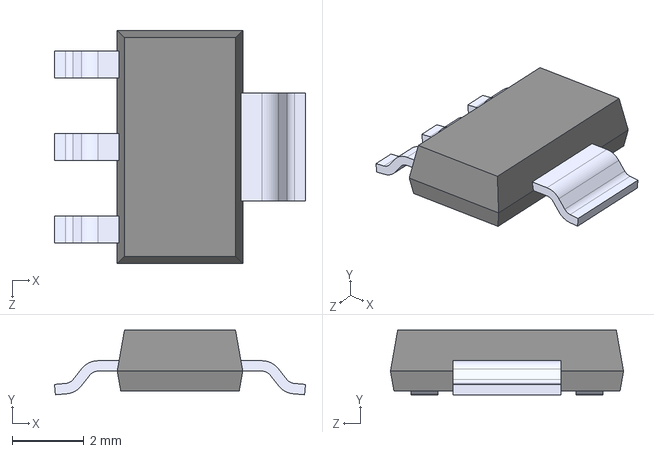
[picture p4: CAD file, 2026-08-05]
KiCad/Custom_Part_Downloads/LM3940IMPX-3.3_NOPB/LM3940IMPX-3.3_NOPB.step
7.00 x 1.80 x 6.50 mm

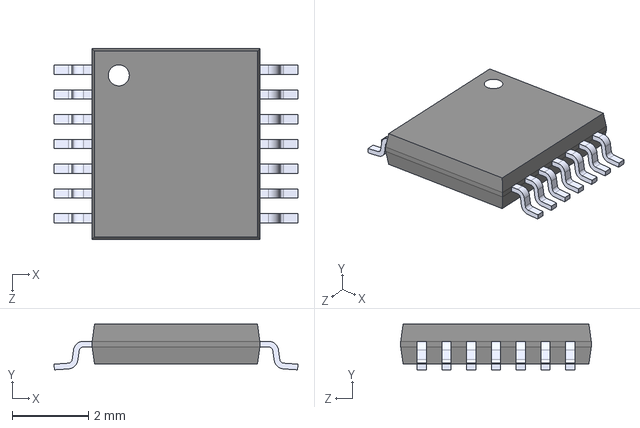
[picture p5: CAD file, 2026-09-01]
KiCad/Custom_Part_Downloads/PCM1808PWG4/PCM1808PWG4.step
6.40 x 1.20 x 5.00 mm

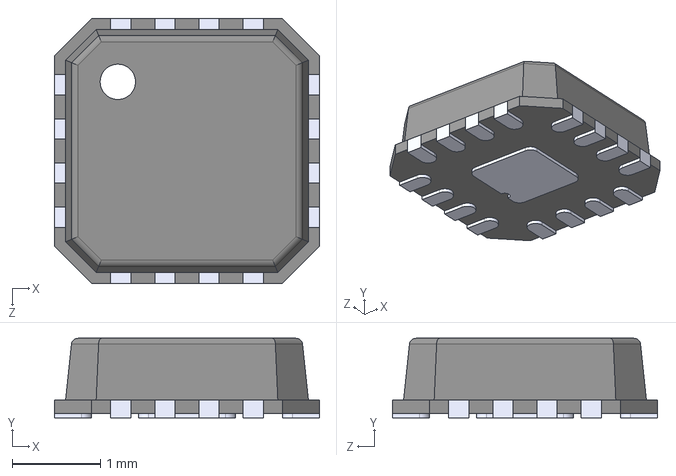
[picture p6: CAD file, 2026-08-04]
KiCad/Custom_Part_Downloads/MAX97220AETE_T/MAX97220AETE_T.step
3.00 x 0.9 x 3.00 mm

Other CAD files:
KiCad/Custom_Part_Downloads/LIB_PTN09S2-H10120K1A/PTN09S2-H10120K1A/Allegro/ptn09s2h10120k1a.psm
KiCad/Custom_Part_Downloads/LIB_PTN09S2-H10120K1A/PTN09S2-H10120K1A/DEHDL/ptn09s2_h10120k1a/chips/chips.prt

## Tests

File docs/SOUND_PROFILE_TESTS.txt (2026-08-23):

SOUND PROFILE ISOLATION TESTS
=============================
Diagnostic sources live under main/debugging/ (not shipping tx.c/rx.c).

Why the old 440 Hz square was a weak LPF detector
-------------------------------------------------
- Fundamental at 440 Hz sits well below any mild treble roll-off.
- A square *does* have odd harmonics (1320, 2200, 3080, …) but a soft LPF
  that starts around 5–8 kHz only nicks the upper buzz. Subjectively it
  can still “sound like a square,” especially on IEMs vs Bluetooth buds
  with totally different transducers.
- Matching Bluetooth 440 Hz in one ear vs IEM in the other only proves
  pitch / rough loudness at one mid frequency — not that 8–12 kHz energy
  survives the path.
- Isolation (single tone, no music reference) also hides dullness: there
  is nothing bright to compare against.

What these builds add
---------------------
1) IEM_NODE=RX_DAC_TEST  → debugging/rx_dac_profile_test.c
   Local PCM5102 only (same 48 kHz / msb_right path as shipping rx.c).
   Cycles: sine_440 → sine_8k → alt_440_8k → square_440 → chirp_200_12k
   (8 s each). No ESP-NOW. USB on RX; TX can stay off.

2) IEM_NODE=TX_TONE  → debugging/tx_tone_bypass.c
   Same pairing / ESP-NOW as shipping TX, but ADC/I2S capture is skipped.
   Digitally generated tones are packed as int16 and sent (esp_timer pace).
   Flash normal IEM_NODE=RX on the receiver.

3) IEM_NODE=TX_BUZZ_DEBUG  → debugging/tx_buzz_debug.c
   Shipping TX capture path + periodic ADC pre-gain peak logs.

Decision table (listen, then pick the row that matches)
-------------------------------------------------------
RX_DAC_TEST sine_8k / chirp dull or dead
  → RX I2S / PCM5102 / FLT / wiring / headphones — not TX ADC or >>16.

RX_DAC_TEST bright, but TX_TONE over air dull
  → Packing / ESP-NOW path / shipping RX playback — not PCM1808 analog.

Both bright, only real laptop/ADC audio dull
  → PCM1808 analog front-end, jack/wiring/breadboard, or source level.

Build / flash
-------------
IEM_NODE=RX_DAC_TEST idf.py reconfigure build flash
IEM_NODE=TX_TONE idf.py reconfigure build flash
IEM_NODE=TX_BUZZ_DEBUG idf.py reconfigure build flash
IEM_NODE=TX|RX idf.py reconfigure build flash   # shipping

See docs/BENCH_REALIZATIONS.txt (CER notes) and main/debugging/README.txt.
EOF

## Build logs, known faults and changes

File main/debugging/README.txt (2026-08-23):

IEM Pack — diagnostic / isolation / archive firmware (not shipping)
====================================================================
Kept for reference after 2026-08-21 sound-profile work and earlier
bring-up. Shipping images build from main/tx.c and main/rx.c only
(IEM_NODE=TX|RX).

Build (from project root):
  IEM_NODE=RX_DAC_TEST   idf.py reconfigure build flash
  IEM_NODE=TX_TONE       idf.py reconfigure build flash
  IEM_NODE=TX_BUZZ_DEBUG idf.py reconfigure build flash

Build targets:
  sound_profile_tones.h   — shared DDS tones + esp_timer packet pace
  rx_dac_profile_test.c   — local PCM5102 tone cycle (no RF)
  tx_tone_bypass.c        — ESP-NOW TX with ADC skipped (TX_TONE_BYPASS_ADC)
  tx_buzz_debug.c         — shipping TX + ADC pre-gain peak logs

Archive / helpers (not wired as IEM_NODE targets):
  square_wave_test.c      — early DAC I2S sanity
  tx_pre.c                — pre-shipping TX draft
  rx_temp_debug.h         — optional RX_DBG macros (included from rx.c)

See docs/SOUND_PROFILE_TESTS.txt and docs/BENCH_REALIZATIONS.txt.

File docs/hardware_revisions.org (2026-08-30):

#+TITLE: Hardware revisions and change log (RX KiCad)
#+AUTHOR: Damian Luciano Muschamp
#+OPTIONS: toc:2 num:nil

* Purpose

Record *what* changed on the RX schematic and *why*, with the evidence
(datasheet / firmware / bench). Use this when re-opening a sheet months later
so you do not re-litigate every net.

Firmware GPIO contract lives in =main/rx.c= / =main/tx.c= on branch =main=
(not on experimental KiCad-only branches that may stub =rx.c=).

* Signal path (RX)

#+BEGIN_SRC
USB-C / power-bank 5V -> LM3940 -> 3V3
CP2102C (bus-powered) <-> ESP32 UART + auto-program (EN / IO0)
ESP32 I2S -> PCM5102 -> (470R + 2.2nF) DAC_OUT
         -> dual-gang pot -> POST_POT -> MAX97220A -> 3.5 mm jack
#+END_SRC

* 2026-08-22 --- review of experimental KiCad fixes branch

Branch under review: =cursor/rx-schematic-wip-fixes-738e= (treat as
experimental). Compared against =main= schematics and datasheets while
editing on the laptop.

** Power management (=pwr_mgmt=)

| Change | Reason / evidence |
|--------+-------------------|
| Keep CP2102C *bus-powered*: =VREGIN= <- USB / power-bank *5V*; =VDD= tied to =VIO=; local 4.7u + 0.1u; =PWR_FLAG= on that rail | CP2102C datasheet Fig 2.1 (bus-powered). Chip is *not* fed from the LM3940 3V3 rail. |
| =R27= 1k pulls =~{RST}= to VDD/VIO | Datasheet: 1k on RSTb to VIO (or VDD when VIO=VDD). |
| Keep =R25=/=R26= 22.1k/47.5k as *VBUS sense divider* (not a VIO divider) | CP2102C / USBXpress VBUS abs-max and VIH notes. |
| Keep LM3940 Cin *22uF* (with optional 0.47uF at IN); do *not* remove bulk to "match" the 0.47uF callout | Datasheet Cin >= 0.47uF is a *minimum*. Larger local bulk is better on a USB/power-bank 5V rail. |
| Keep Cout *33uF* (ESR in band); optional bump to 47uF same chemistry | Datasheet minimum 33uF; larger helps transients but ESR still rules. Prefer tantalum / correct ESR over a lone low-ESR 0805 ceramic. |
| =PWR_FLAG= on CP2102 VDD does *not* mean global board =+3V3= | Flag only satisfies ERC "net is driven". Pack 3V3 remains LM3940 =OUT=. |

** ESP32 sheet (=esp_rx=)

| Change | Reason / evidence |
|--------+-------------------|
| Prefer redraw / fresh symbol over salvaging post-rotate wiring | Rotating a symbol moves pin *positions*; labels do not stay bound to pin *names*. |
| Hier labels =BCK=/=LRCLK=/=DOUT=/=TXD=/=RXD=/=ESP_EN=/=ESP_IO0= must match other sheets *exactly* | Hierarchical labels are the same net across sheets; name mismatch = open net. |
| =DOUT= on *GPIO25* (module pin for IO25); not GPIO35 | =main/rx.c=: =DOUT_PIN 35= is *wrong for RX*. RX uses =DOUT_PIN 25=. TX uses =DIN_PIN 35= (input-only) on the TX board. |
| UART crossed: ESP =TXD0/IO1= net =TXD= -> CP2102 *RXD*; ESP =RXD0/IO3= net =RXD= -> CP2102 *TXD* | Standard UART cross; DevKit-style USB-UART. |
| =ESP_EN= / =ESP_IO0= at the EN/IO0 junctions (pull-ups + transistor collectors) | Espressif DevKitC auto-program + esptool boot-mode docs. Transistors *pull low*; 10k pull-ups hold high for run mode. |
| EN: 10k to 3V3 + ~0.1uF to GND (DevKit-like). IO0: 10k to 3V3; *no* large C to GND | Official DevKit puts the reset timing C on *EN*, not a fat cap on IO0. |
| =ANT1= U.FL pigtail = BOM / documentation only | WROOM-32U has on-module U.FL; no GPIO antenna net. |

Refs:
- https://docs.espressif.com/projects/esptool/en/latest/esp32/advanced-topics/boot-mode-selection.html
- ESP32-DevKitC schematic (auto program truth table)

** DAC sheet (=dac=)

| Change | Reason / evidence |
|--------+-------------------|
| *Restored* =dac.kicad_sch= from branch =main= (discarded experimental "broken" wiring) | Experimental pass had attached I2S nets to =DEMP=/=FLT=/=XSMT=/=FMT= and put FLT/XSMT switches on =BCK=/=DIN= --- classic rotate damage. Pre-fix ("old") topology matched the PCM5102 datasheet. |
| Renamed hier label =DIN= -> =DOUT= (still wired to PCM5102 pin *DIN*) | Matches =rx.c= =DOUT_PIN=. Chip pin name stays DIN (DAC data *in*). |
| Keep SW2 -> =FLT=, SW3 -> =XSMT=; =SCK= to GND (PLL mode) | PCM5102 datasheet config pins; grounding SCK selects internal PLL. |
| Keep analog out filter: =OUTL/OUTR= -> 470R -> =DAC_OUT_*=, 2.2nF to GND | Already matched PCM5102 recommended network for ~10k load. No change needed. |

** Volume / pre-pot divider (=vol_ctrl=)

| Change | Reason / evidence |
|--------+-------------------|
| Do *not* require an extra resistive pad before the pot | PCM5102 already filters on the DAC sheet. The dual-gang pot *is* the volume divider. |
| Experimental 1k/10R (~40 dB) pad: leave *DNP*; short across the 1k so the path is not open | Bench experiment, not datasheet-required. With DNP + short, pot input ~= filtered =DAC_OUT=. |
| Can treat pre-pot audio as =DAC_OUT_L/R= feeding the pot directly | Same electrical idea: no extra attenuation stage. Keep the *pot* (and 0% =SHDN= switch). Do *not* wire =DAC_OUT= straight into the amp unless you want fixed full volume. |

** Amp sheet (=amp=)

| Change | Reason / evidence |
|--------+-------------------|
| Restored topology from =main= / pre-fix amp (jack on =OUTL=/=OUTR=, pseudo-diff input from =POST_POT_IN_*=) | Experimental "mixed" sheet had label/shift issues; old connectivity was the intended MAX97220A path. |
| Mark =R1=--=R6=, =R9=, =R10= as *DNP* (Do Not Populate) for hand-built protos | =MAX97220A= (A/B/E) sets gain externally: =AV = -RF/RIN= (datasheet Fig 5; RF 4.7k--100k). These Rs *are* the gain network for the A part (pseudo-diff / single-ended app circuit). =C=/=D= are fixed +6 dB --- wrong if you want bench-tuned max loudness. Populate matched ~10k to start on a fully assembled board. |
| Keep =SHDN_SIGNAL= from dual-gang pot for true 0% volume | Active-low shutdown; better than DAC soft-mute alone for "off". |
| Keep =R22= 100k from =SHDN_SIGNAL= to GND | Not a pot-datasheet value. MAX97220 =~{SHDN}= must be *driven* high to run / low to shut down (VIH 1.4 V, VIL 0.4 V, ~1 uA leakage) --- it must not float. Pot switch (PTN09) is mechanical only: =COM= <- +3V3, =N.O.= -> =SHDN=. At full CCW the switch opens; 100k pulls =~{SHDN}= low so the amp stays off. When you turn up, =N.O.= closes and hard-ties =SHDN= to 3V3 (~33 uA through 100k). 10k--1M also works; 100k is a weak default. |

** Process / tooling notes

| Change | Reason / evidence |
|--------+-------------------|
| Experimental KiCad branch may stub =main/rx.c= | That branch is schematic-focused; firmware source of truth is =origin/main=. Restore with =git checkout main -- main/....= if needed. |
| Prefer screenshots in =~/Pictures= + this log over committing huge PDFs | Datasheets can be fetched; *your* wiring is what must be reviewed. Optional local =docs/spec_sheets/= is fine if gitignored. |

* 2026-08-30 --- gain network, coupling caps, ESD clamp

** Amp (=amp=)

| Change | Reason / evidence |
|--------+-------------------|
| =R1=/=R3=/=R9=/=R10= -> *4.7k*, =R2=/=R4=/=R5=/=R6= -> *47k*, all *populated* (no longer DNP) | =AV = -RF/RIN= = -20 dB. Fixes three things at once: tames the DAC's 2.1 Vrms into sensitive IEMs, gives the 10k pot a 4.7x loading ratio instead of 1:1, and moves the coupling corner off the audible band. An unpopulated =RF= is *not* a safe default --- it leaves the amp open loop. |
| =C1=--=C4= 0.47uF -> *1uF* (all four, X7R min.) | Corner 7.2 Hz -> 3.4 Hz, -0.53 dB -> -0.12 dB at 20 Hz. Also halves the signal developed across the ceramic at 20 Hz (34% -> 17%), reducing Class-II dielectric distortion where it actually occurs. =C2=/=C3= are the matching =IN+= legs and must track =C1=/=C4= or LF CMRR degrades. Same 0805 footprint --- value-only change. |
| Stop at 1uF, do not fit 2.2uF | 1.54 Hz corner buys only +0.09 dB and passes more subsonic rumble / DC drift. Convention is a 3--5 Hz coupling corner. |
| =C28= 1uF added on +3V3/GND | Amp sheet omitted pin 13; part existed on the PCB with no schematic counterpart (parity error). |

** Power management (=pwr_mgmt=)

| Change | Reason / evidence |
|--------+-------------------|
| =D1= pin 2 moved from =+5V= to the connector-side rail, now named =VBUS_RAW= | =SP0503BAHT= is a 4-line TVS (common anode, three cathodes). The =D+=/=D-= cathodes were already correct; the third was clamping the rail *after* =SW4=, so with the switch OFF the exposed =J6= VBUS pin had no clamp --- unprotected exactly when the board is most likely to be handled and unplugged. Does not affect the OFF state: a TVS is open below its standoff voltage, and =SW4= still breaks the rail to =U4=/=U5=. |
| Pulldowns =R31=/=R32= 100k on =FLT_SEL= / =XSMT_SEL=; =DEMP= and =FMT= strapped to GND | PCM5102 mode pins must not float with the switches open. |
| =SW3= (soft mute): =XSMT_SEL= moved from pin 3 to pin 1, NC flag moved pin 3 | All three switches are SPDT with *pin 2 (B) as the common*; the unwired throw is the rest position. =SW3= is placed rot 90, so pin 1 is NORTH and pin 3 is SOUTH. Wanted SOUTH = mute, so SOUTH must be the *open* throw (pulled low by =R32= = muted). Was backwards. |

Design convention now consistent across all three switches: *the open throw is
the safe default* --- =SW4= open = powered off, =SW2= open = normal-latency FIR
("quality") filter, =SW3= open = muted. Enabling anything requires deliberately
sliding onto the +V throw.
| 4x =Mechanical:MountingHole= (=REF1=--=REF4=) added to root sheet | Were PCB-only; showed as =extra_footprint= schematic-parity errors. |

*** Follow-up required in KiCad

The =D1= change is a *netlist* change, so the PCB is now out of date. Run *Update
PCB from Schematic*, then rip up and reroute the single trace from =D1= pad 2 ---
it is still on the =+5V= copper. The cap value changes need no layout work.

* Open / next

- Reroute =D1= pad 2 to =VBUS_RAW= on the PCB (see above), then re-run DRC with
  =--schematic-parity --severity-all=.
- Finish =vol_ctrl= cleanup (confirm DNP pad + =DAC_OUT= -> pot).
- Amp visual ERC / label pass after restore.
- Then TX schematic (mirror shared power / ESP / antenna; PCM1808 instead of PCM5102).
- PCB layout after both schematics are stable.

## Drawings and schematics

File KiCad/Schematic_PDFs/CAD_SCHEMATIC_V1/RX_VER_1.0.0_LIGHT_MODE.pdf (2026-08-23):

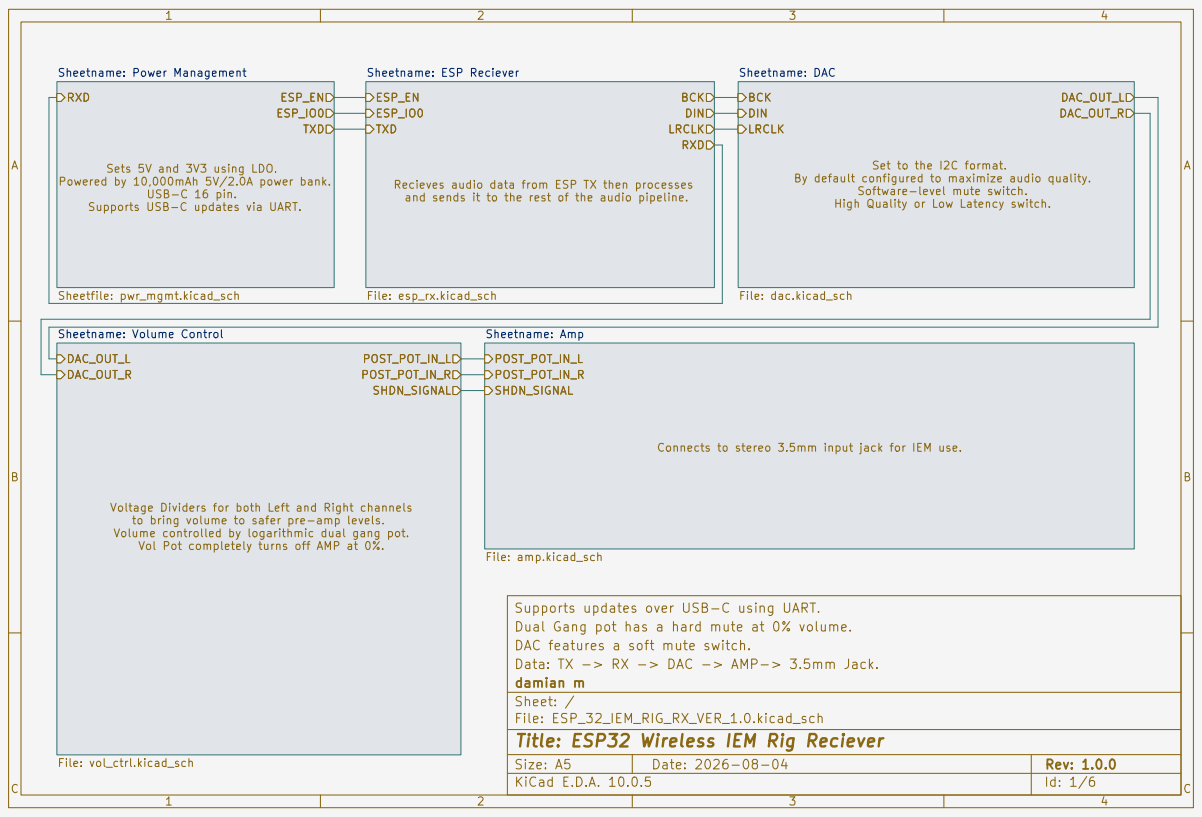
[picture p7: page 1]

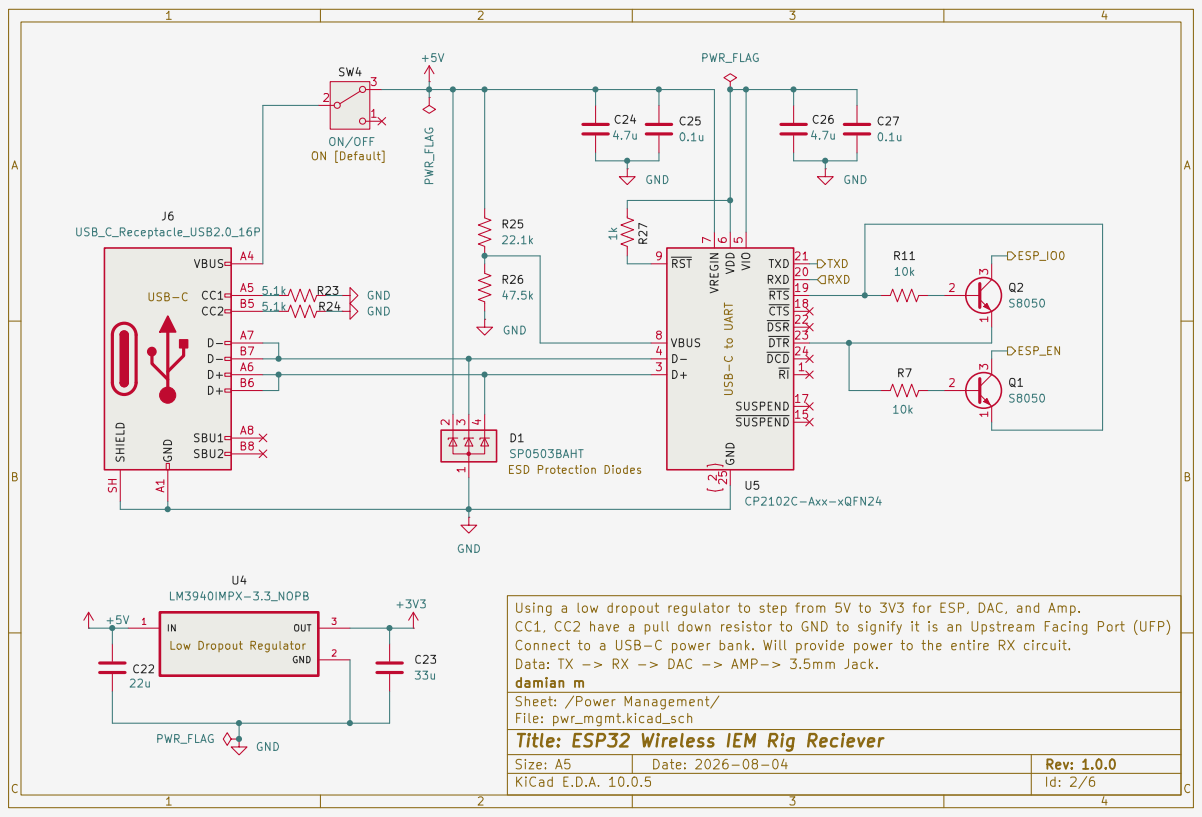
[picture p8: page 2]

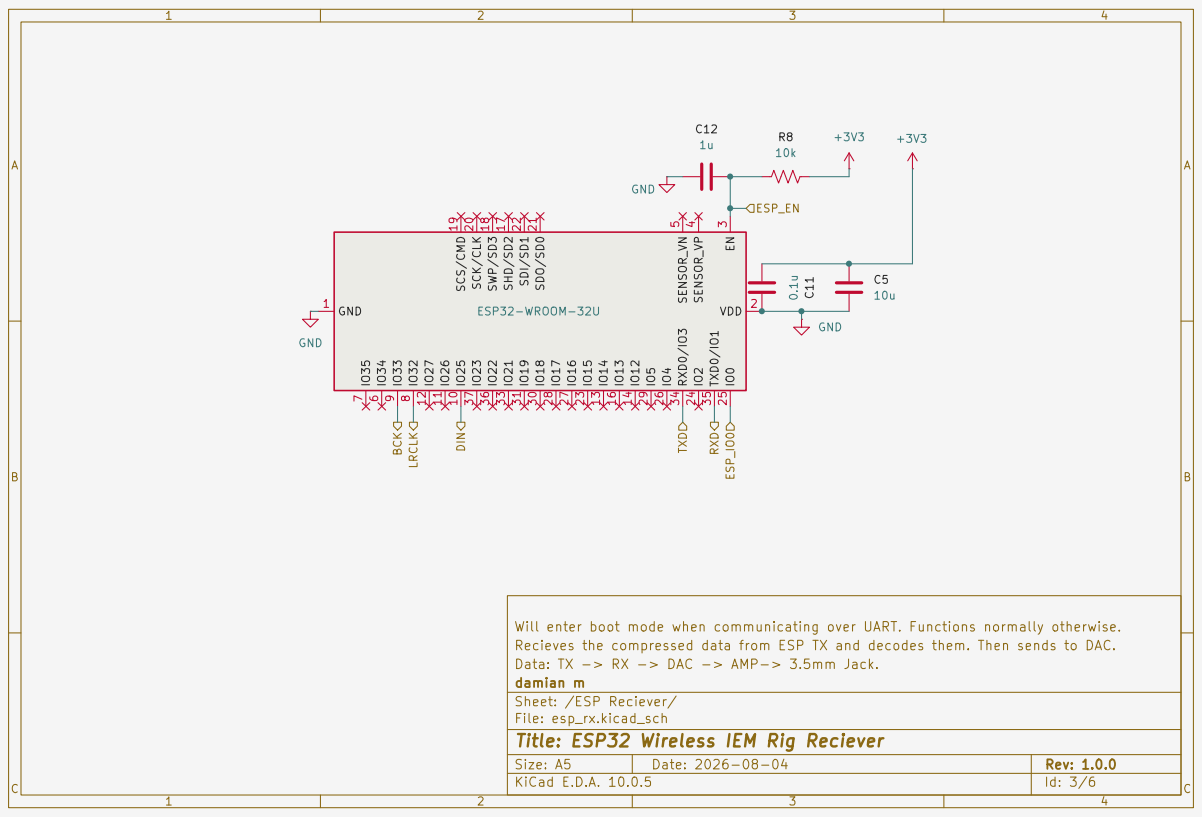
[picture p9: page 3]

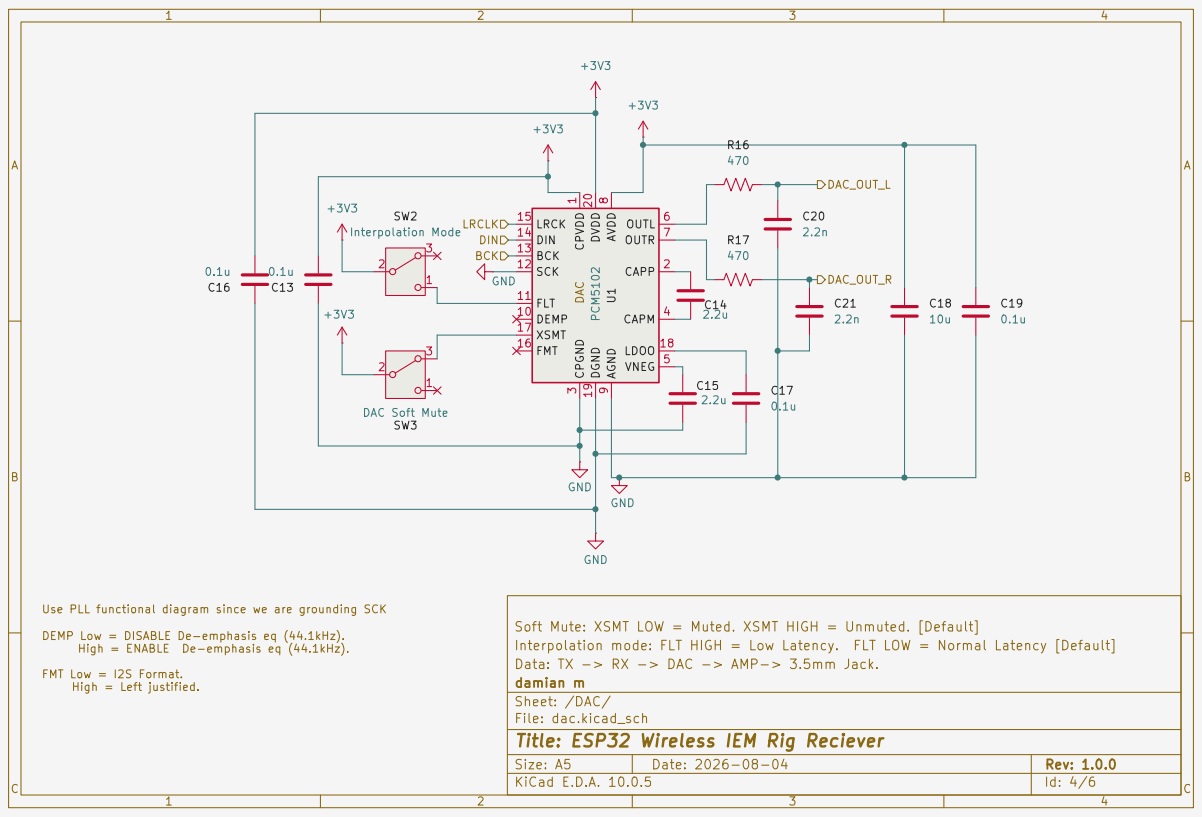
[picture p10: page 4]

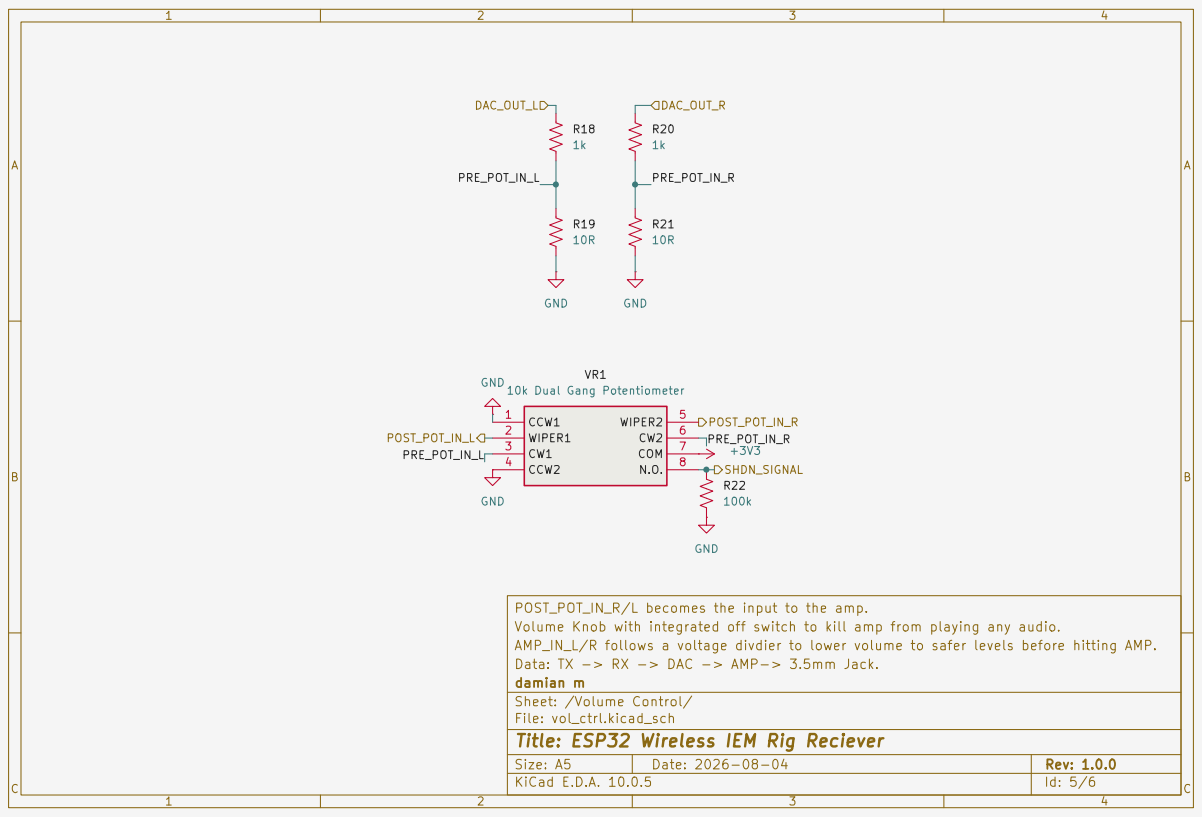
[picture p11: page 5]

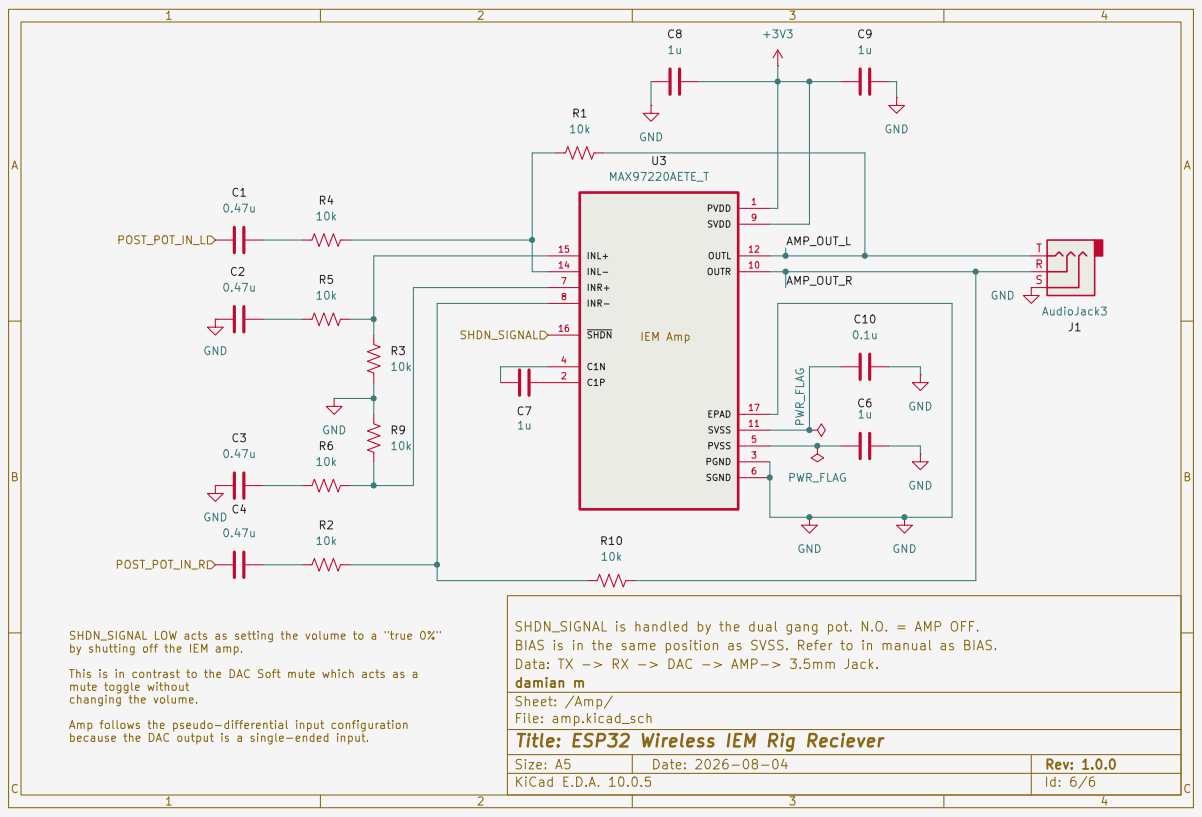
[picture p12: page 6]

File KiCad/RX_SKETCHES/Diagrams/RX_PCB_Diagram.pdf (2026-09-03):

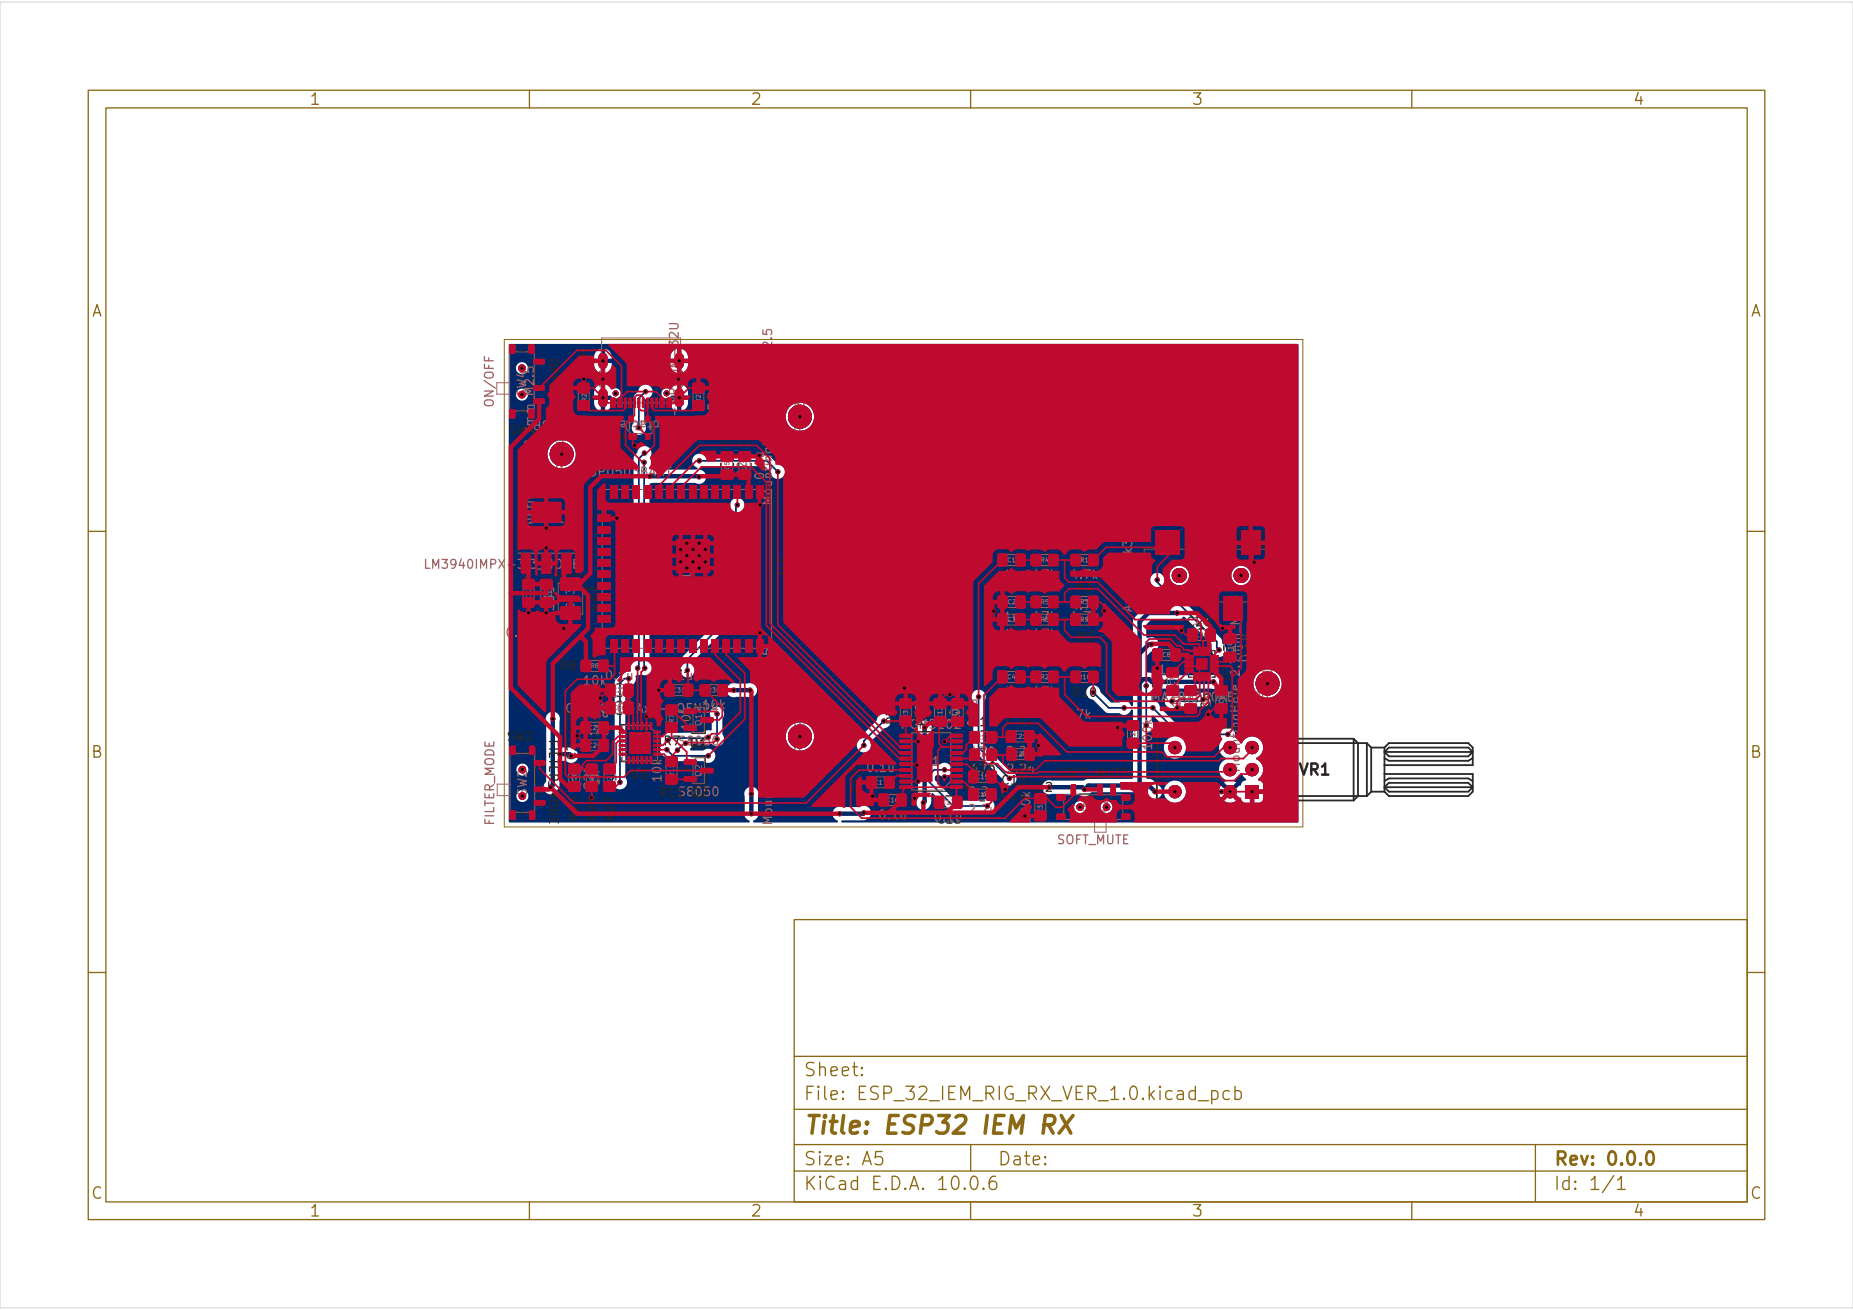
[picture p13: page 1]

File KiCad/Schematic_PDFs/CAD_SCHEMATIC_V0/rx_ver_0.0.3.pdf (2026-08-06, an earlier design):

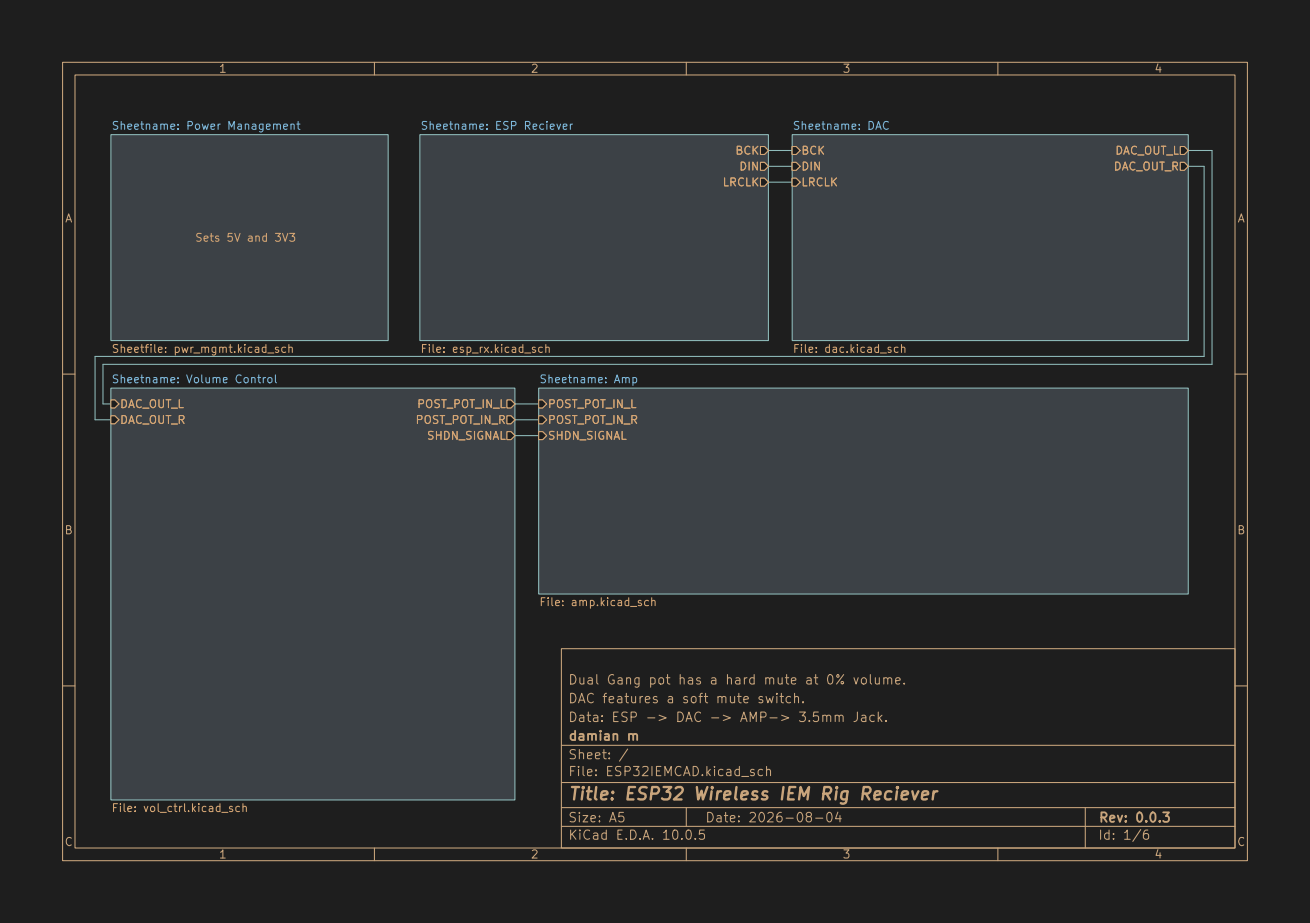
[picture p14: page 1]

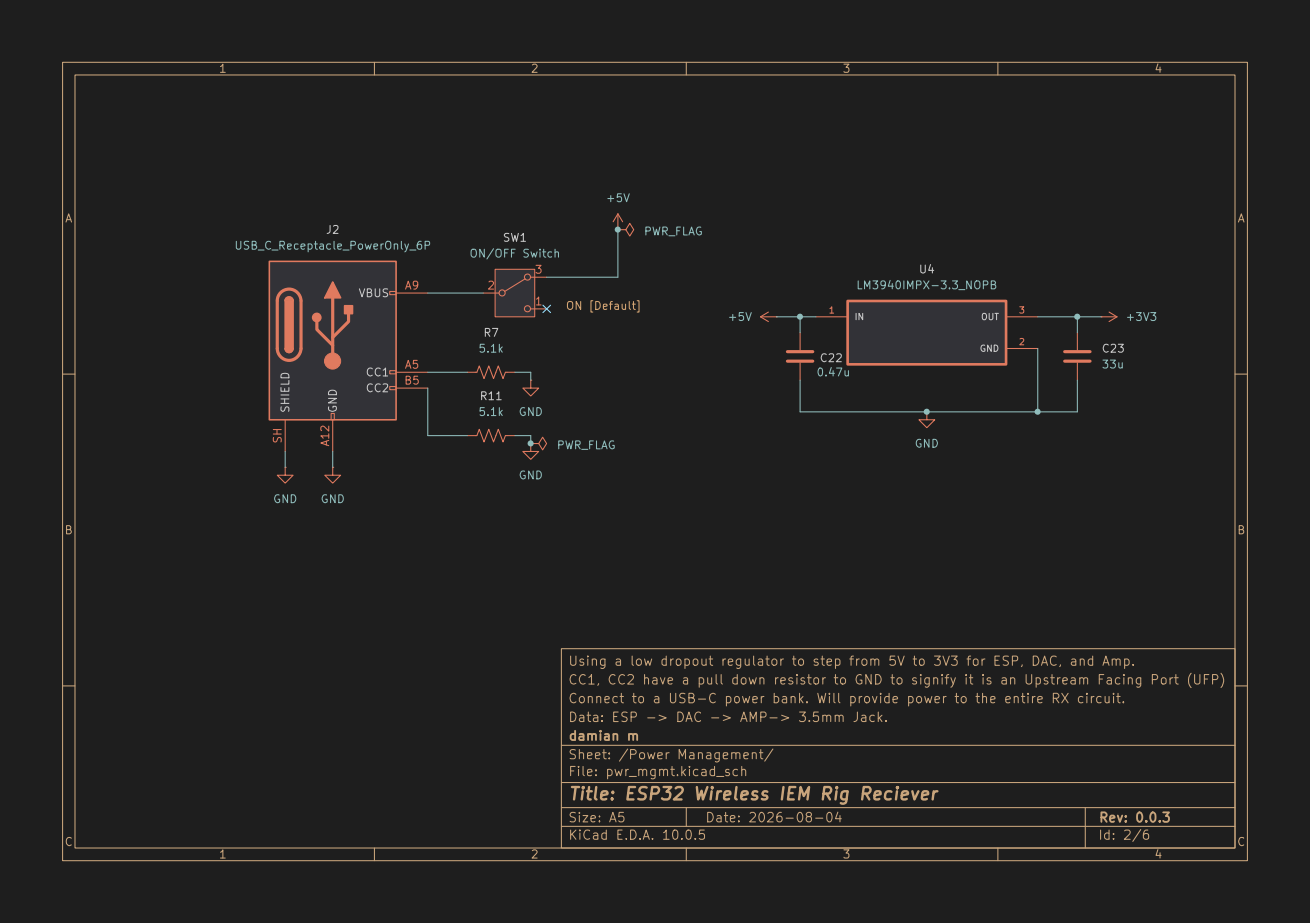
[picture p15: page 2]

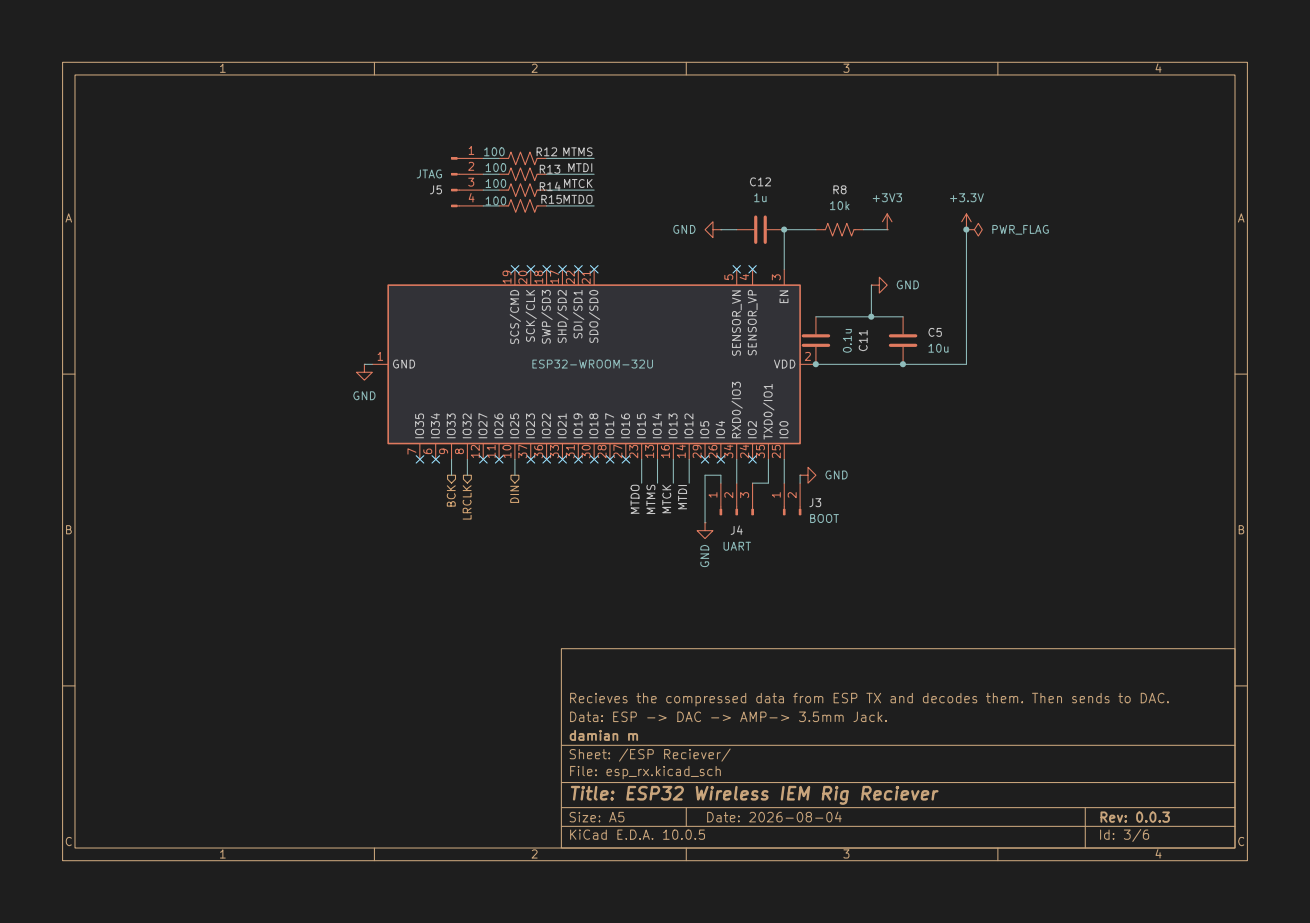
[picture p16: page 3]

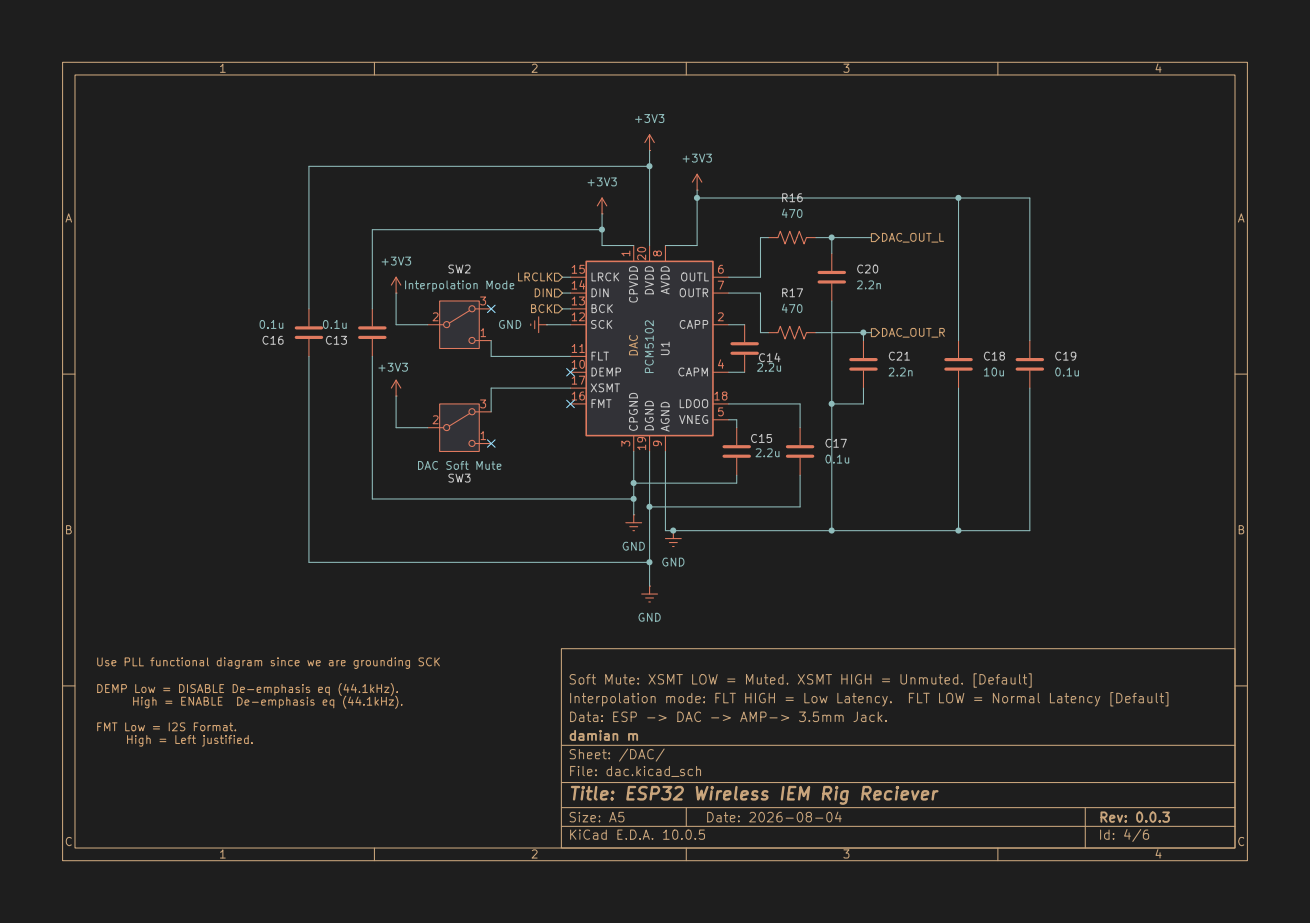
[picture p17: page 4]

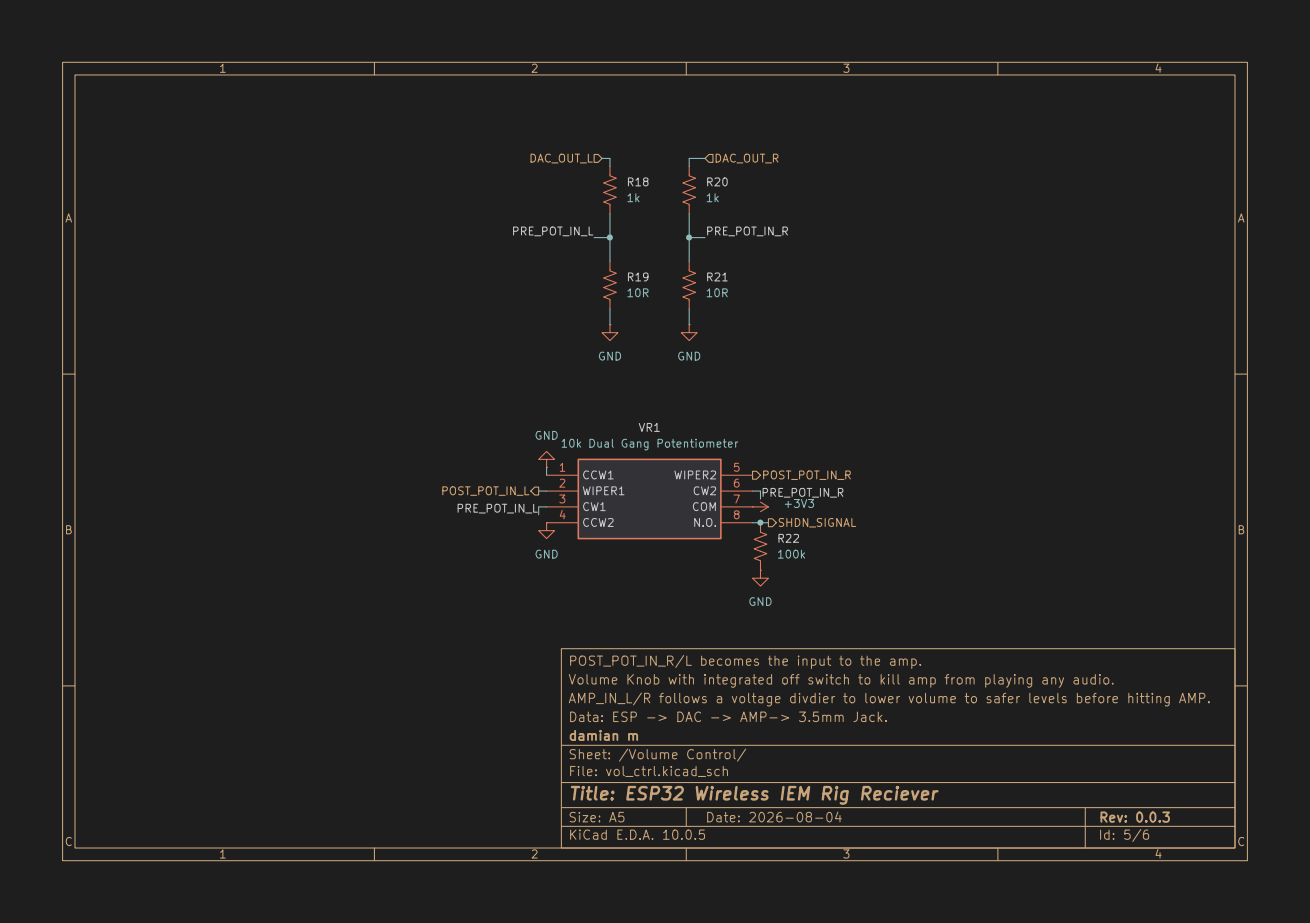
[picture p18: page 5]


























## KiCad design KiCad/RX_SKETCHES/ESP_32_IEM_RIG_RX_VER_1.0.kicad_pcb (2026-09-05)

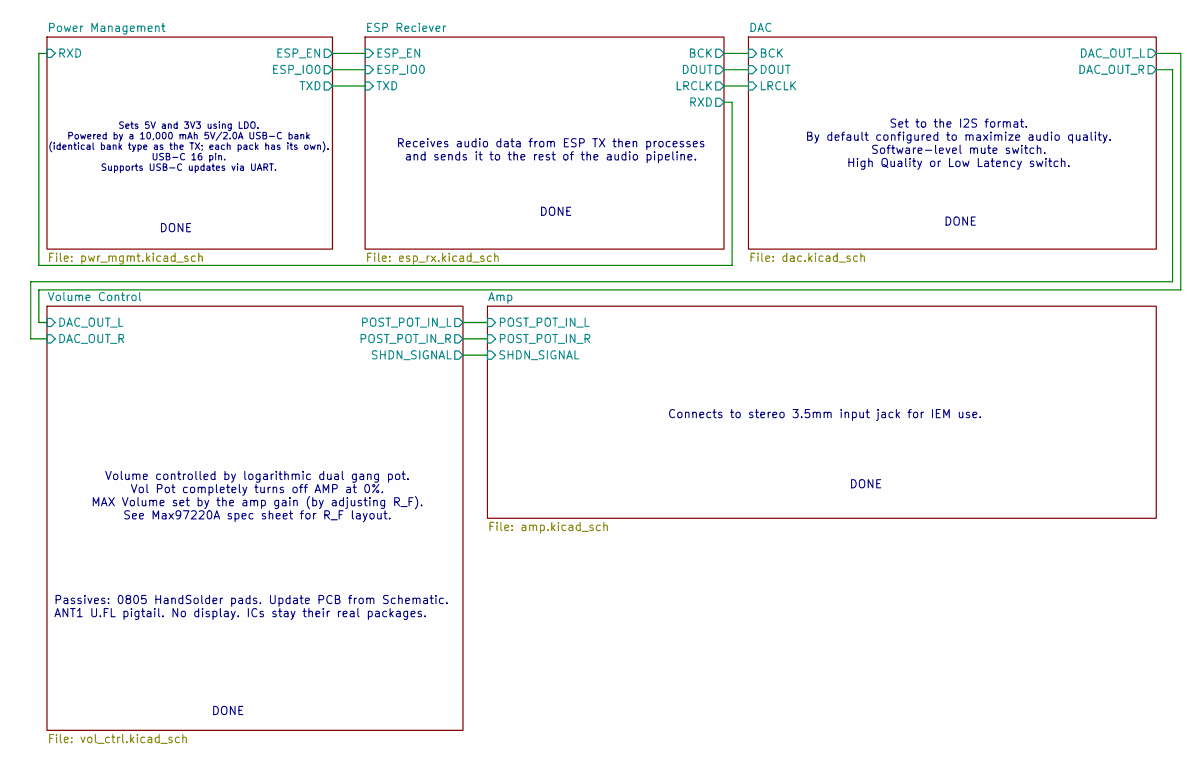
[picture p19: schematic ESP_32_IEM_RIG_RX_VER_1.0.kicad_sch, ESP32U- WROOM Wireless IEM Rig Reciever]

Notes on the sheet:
DONE
Volume controlled by logarithmic dual gang pot. Vol Pot completely turns off AMP at 0%. MAX Volume set by the amp gain (by adjusting R_F). See Max97220A spec sheet for R_F layout.
Receives audio data from ESP TX then processes and sends it to the rest of the audio pipeline.
Connects to stereo 3.5mm input jack for IEM use.
Passives: 0805 HandSolder pads. Update PCB from Schematic. ANT1 U.FL pigtail. No display. ICs stay their real packages.
Sets 5V and 3V3 using LDO. Powered by a 10,000 mAh 5V/2.0A USB-C bank (identical bank type as the TX; each pack has its own). USB-C 16 pin. Supports USB-C updates via UART.
Set to the I2S format. By default configured to maximize audio quality. Software-level mute switch. High Quality or Low Latency switch.

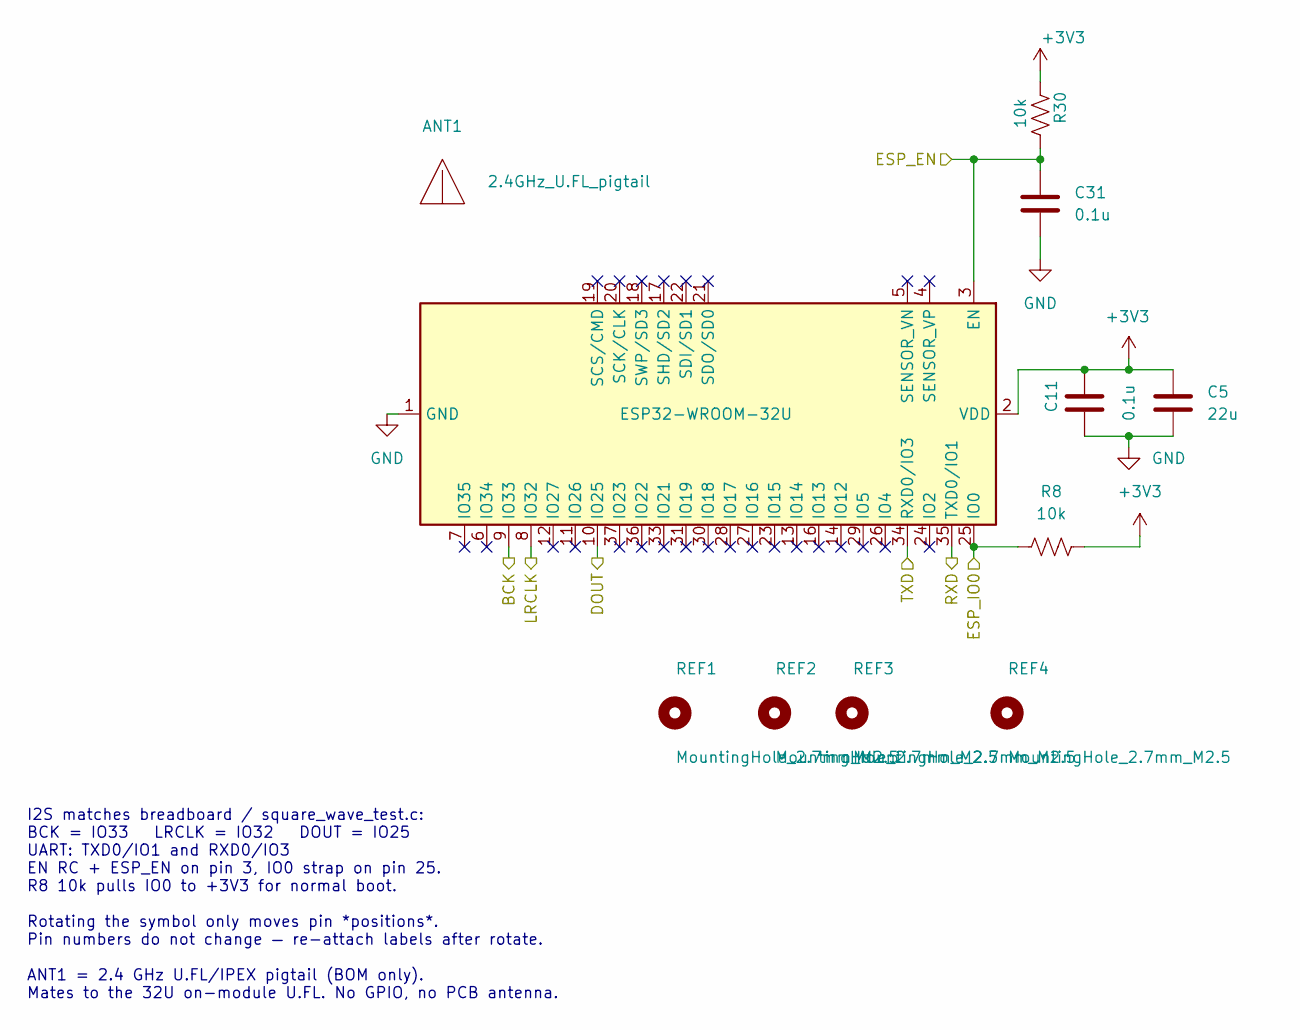
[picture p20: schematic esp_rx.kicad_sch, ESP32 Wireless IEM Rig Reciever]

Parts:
ANT1: 2.4GHz_U.FL_pigtail
C5: 22u; C_0805_2012Metric_Pad1.18x1.45mm_HandSolder
C11, C31: 0.1u; C_0805_2012Metric_Pad1.18x1.45mm_HandSolder
R8, R30: 10k; R_0805_2012Metric_Pad1.20x1.40mm_HandSolder
REF1, REF2, REF3, REF4: MountingHole_2.7mm_M2.5
U2: ESP32-WROOM-32U

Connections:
+3V3: C5.1, C11.1, R8.1, R30.2, U2.2 (VDD); also elsewhere on the board
/DAC/BCK: U2.9 (IO33); also elsewhere on the board
/DAC/DOUT: U2.10 (IO25); also elsewhere on the board
/DAC/LRCLK: U2.8 (IO32); also elsewhere on the board
/ESP Reciever/ESP_EN: C31.1, R30.1, U2.3 (EN); also elsewhere on the board
/ESP Reciever/ESP_IO0: R8.2, U2.25 (IO0); also elsewhere on the board
/ESP Reciever/RXD: U2.35 (TXD0/IO1); also elsewhere on the board
/ESP Reciever/TXD: U2.34 (RXD0/IO3); also elsewhere on the board
GND: C5.2, C11.2, C31.2, U2.1 (GND), U2.15 (GND), U2.38 (GND), U2.39 (GND); also elsewhere on the board

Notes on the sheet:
I2S matches breadboard / square_wave_test.c: BCK = IO33 LRCLK = IO32 DOUT = IO25 UART: TXD0/IO1 and RXD0/IO3 EN RC + ESP_EN on pin 3, IO0 strap on pin 25. R8 10k pulls IO0 to +3V3 for normal boot. Rotating the symbol only moves pin *positions*. Pin numbers do not change — re-attach labels after rot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

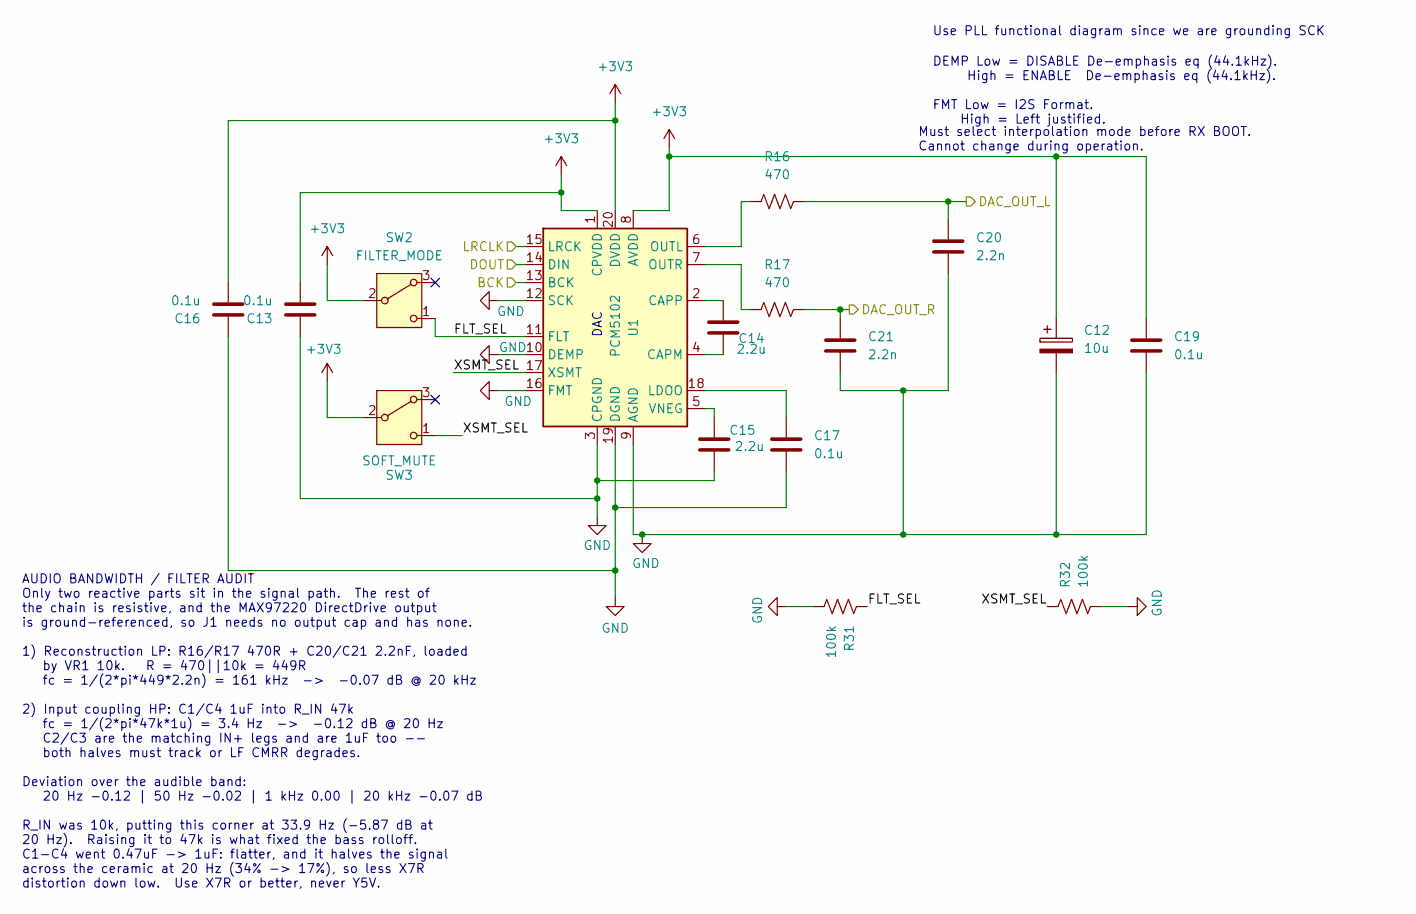
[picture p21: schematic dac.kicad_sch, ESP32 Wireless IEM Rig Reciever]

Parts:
C12: 10u; C_0805_2012Metric_Pad1.18x1.45mm_HandSolder
C13, C16, C17, C19: 0.1u; C_0805_2012Metric_Pad1.18x1.45mm_HandSolder
C14, C15: 2.2u; C_0805_2012Metric_Pad1.18x1.45mm_HandSolder
C20, C21: 2.2n; C_0805_2012Metric_Pad1.18x1.45mm_HandSolder
R16, R17: 470; R_0805_2012Metric_Pad1.20x1.40mm_HandSolder
R31, R32: 100k; R_0805_2012Metric_Pad1.20x1.40mm_HandSolder
SW2: FILTER_MODE; SW_SPDT_Shouhan_MSK12C02
SW3: SOFT_MUTE; SW_SPDT_Shouhan_MSK12C02
U1: PCM5102; TSSOP-20_4.4x6.5mm_P0.65mm

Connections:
+3V3: C12.1, C13.2, C16.2, C19.1, SW2.2 (B), SW3.2 (B), U1.1 (CPVDD), U1.8 (AVDD), U1.20 (DVDD); also elsewhere on the board
/DAC/BCK: U1.13 (BCK); also elsewhere on the board
/DAC/DAC_OUT_L: C20.1, R16.2; also elsewhere on the board
/DAC/DAC_OUT_R: C21.1, R17.2; also elsewhere on the board
/DAC/DOUT: U1.14 (DIN); also elsewhere on the board
/DAC/FLT_SEL: R31.1, SW2.1 (C), U1.11 (FLT)
/DAC/LRCLK: U1.15 (LRCK); also elsewhere on the board
/DAC/XSMT_SEL: R32.1, SW3.1 (C), U1.17 (XSMT)
GND: C12.2, C13.1, C15.2, C16.1, C17.2, C19.2, C20.2, C21.2, R31.2, R32.2, U1.3 (CPGND), U1.9 (AGND), U1.10 (DEMP), U1.12 (SCK), U1.16 (FMT), U1.19 (DGND); also elsewhere on the board
unnamed: C14.2, U1.4 (CAPM)
unnamed: C14.1, U1.2 (CAPP)
unnamed: C17.1, U1.18 (LDOO)
unnamed: R16.1, U1.6 (OUTL)
unnamed: R17.1, U1.7 (OUTR)
unnamed: C15.1, U1.5 (VNEG)

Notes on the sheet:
AUDIO BANDWIDTH / FILTER AUDIT Only two reactive parts sit in the signal path. The rest of the chain is resistive, and the MAX97220 DirectDrive output is ground-referenced, so J1 needs no output cap and has none. 1) Reconstruction LP: R16/R17 470R + C20/C21 2.2nF, loaded by VR1 10k. R = 470||10k = 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
DAC
DEMP Low = DISABLE De-emphasis eq (44.1kHz). High = ENABLE De-emphasis eq (44.1kHz). FMT Low = I2S Format. High = Left justified.
Use PLL functional diagram since we are grounding SCK
Must select interpolation mode before RX BOOT. Cannot change during operation.

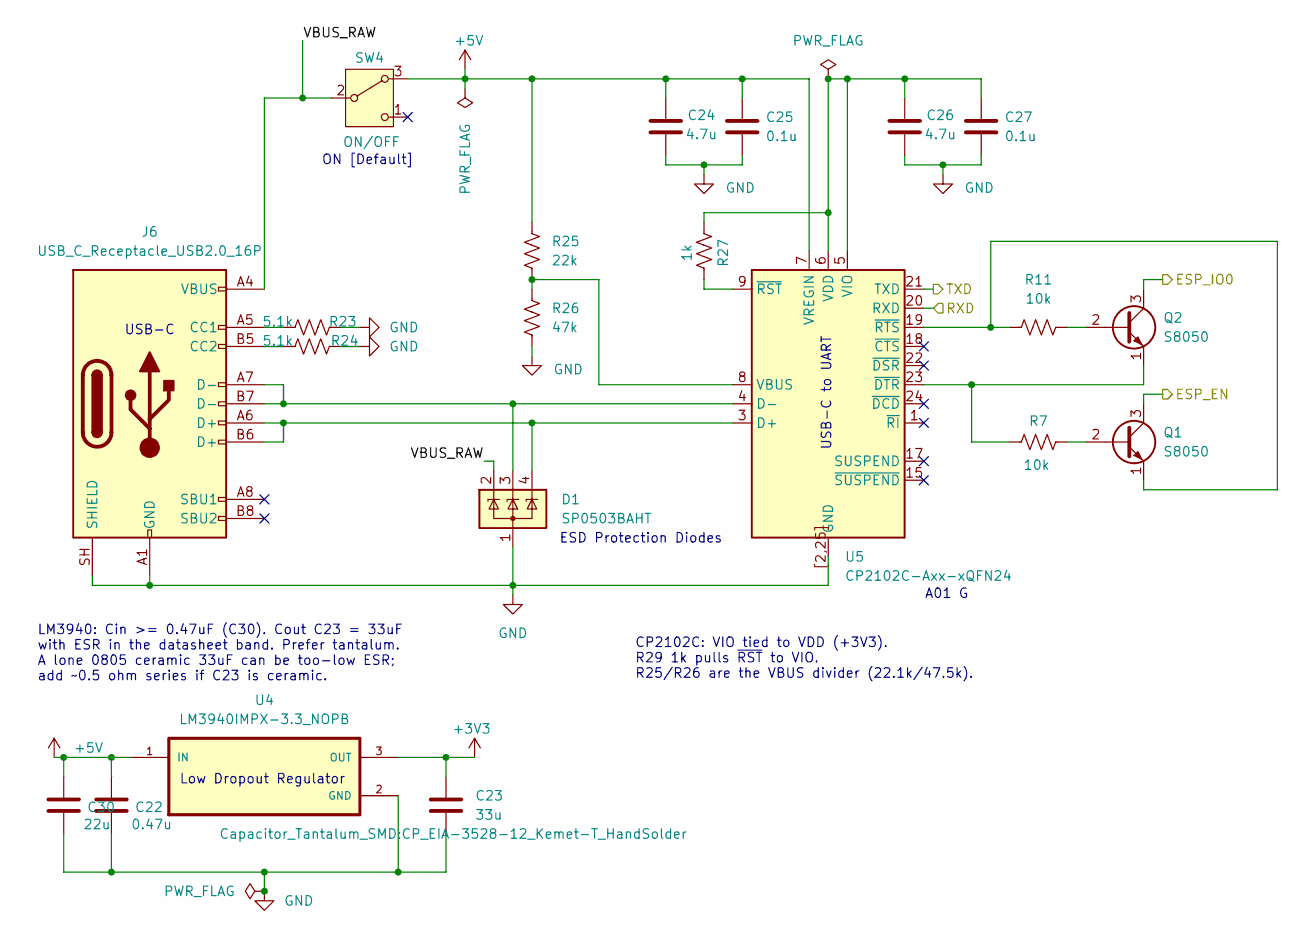
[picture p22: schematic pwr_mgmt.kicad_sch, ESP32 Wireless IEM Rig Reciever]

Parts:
C22: 0.47u; C_0805_2012Metric_Pad1.18x1.45mm_HandSolder
C23: 33u; CP_EIA-3528-12_Kemet-T_HandSolder
C24, C26: 4.7u; C_0805_2012Metric_Pad1.18x1.45mm_HandSolder
C25, C27: 0.1u; C_0805_2012Metric_Pad1.18x1.45mm_HandSolder
C30: 22u; C_0805_2012Metric_Pad1.18x1.45mm_HandSolder
D1: SP0503BAHT; SOT-143
J6: USB_C_Receptacle_USB2.0_16P; USB_C_Receptacle_GCT_USB4105-xx-A_16P_TopMnt_Horizontal
Q1, Q2: S8050; SOT-23
R7, R11: 10k; R_0805_2012Metric_Pad1.20x1.40mm_HandSolder
R23, R24: 5.1k; R_0805_2012Metric_Pad1.20x1.40mm_HandSolder
R25: 22k; R_0805_2012Metric_Pad1.20x1.40mm_HandSolder
R26: 47k; R_0805_2012Metric_Pad1.20x1.40mm_HandSolder
R27: 1k; R_0805_2012Metric_Pad1.20x1.40mm_HandSolder
SW4: ON/OFF; SW_SPDT_Shouhan_MSK12C02
U4: LM3940IMPX-3.3_NOPB; SOT230P700X180-4N
U5: CP2102C-Axx-xQFN24; WQFN-24-1EP_4x4mm_P0.5mm_EP2.45x2.45mm

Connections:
+3V3: C23.1, U4.3 (OUT); also elsewhere on the board
+5V: C22.1, C24.1, C25.1, C30.1, R25.1, SW4.3 (A), U4.1 (IN), U5.7 (VREGIN)
/ESP Reciever/ESP_EN: Q1.3 (C); also elsewhere on the board
/ESP Reciever/ESP_IO0: Q2.3 (C); also elsewhere on the board
/ESP Reciever/RXD: U5.20 (RXD); also elsewhere on the board
/ESP Reciever/TXD: U5.21 (TXD); also elsewhere on the board
/Power Management/VBUS_RAW: D1.2 (K), J6.A4 (VBUS), J6.A9 (VBUS), J6.B4 (VBUS), J6.B9 (VBUS), SW4.2 (B)
GND: C22.2, C23.2, C24.2, C25.2, C26.2, C27.2, C30.2, D1.1 (A), J6.A1 (GND), J6.A12 (GND), J6.B1 (GND), J6.B12 (GND), J6.SH (SHIELD), R23.2, R24.2, R26.2, U4.2 (GND), U4.4 (GND), U5.2 (GND), U5.25 (GND), U5.[2,25] (GND); also elsewhere on the board
unnamed: J6.A5 (CC1), R23.1
unnamed: J6.B5 (CC2), R24.1
unnamed: Q1.2 (B), R7.2
unnamed: Q1.1 (E), R11.1, U5.19 (~RTS)
unnamed: Q2.2 (B), R11.2
unnamed: Q2.1 (E), R7.1, U5.23 (~DTR)
unnamed: D1.4 (K), J6.A6 (D+), J6.B6 (D+), U5.3 (D+)
unnamed: D1.3 (K), J6.A7 (D-), J6.B7 (D-), U5.4 (D-)
unnamed: R25.2, R26.1, U5.8 (VBUS)
unnamed: C26.1, C27.1, R27.2, U5.5 (VIO), U5.6 (VDD)
unnamed: R27.1, U5.9 (~RST)

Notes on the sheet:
A01 G
USB-C
LM3940: Cin >= 0.47uF (C30). Cout C23 = 33uF with ESR in the datasheet band. Prefer tantalum. A lone 0805 ceramic 33uF can be too-low ESR; add ~0.5 ohm series if C23 is ceramic.
Low Dropout Regulator
ON [Default]
ESD Protection Diodes
USB-C to UART
CP2102C: VIO tied to VDD (+3V3). R29 1k pulls ~{RST} to VIO. R25/R26 are the VBUS divider (22.1k/47.5k).

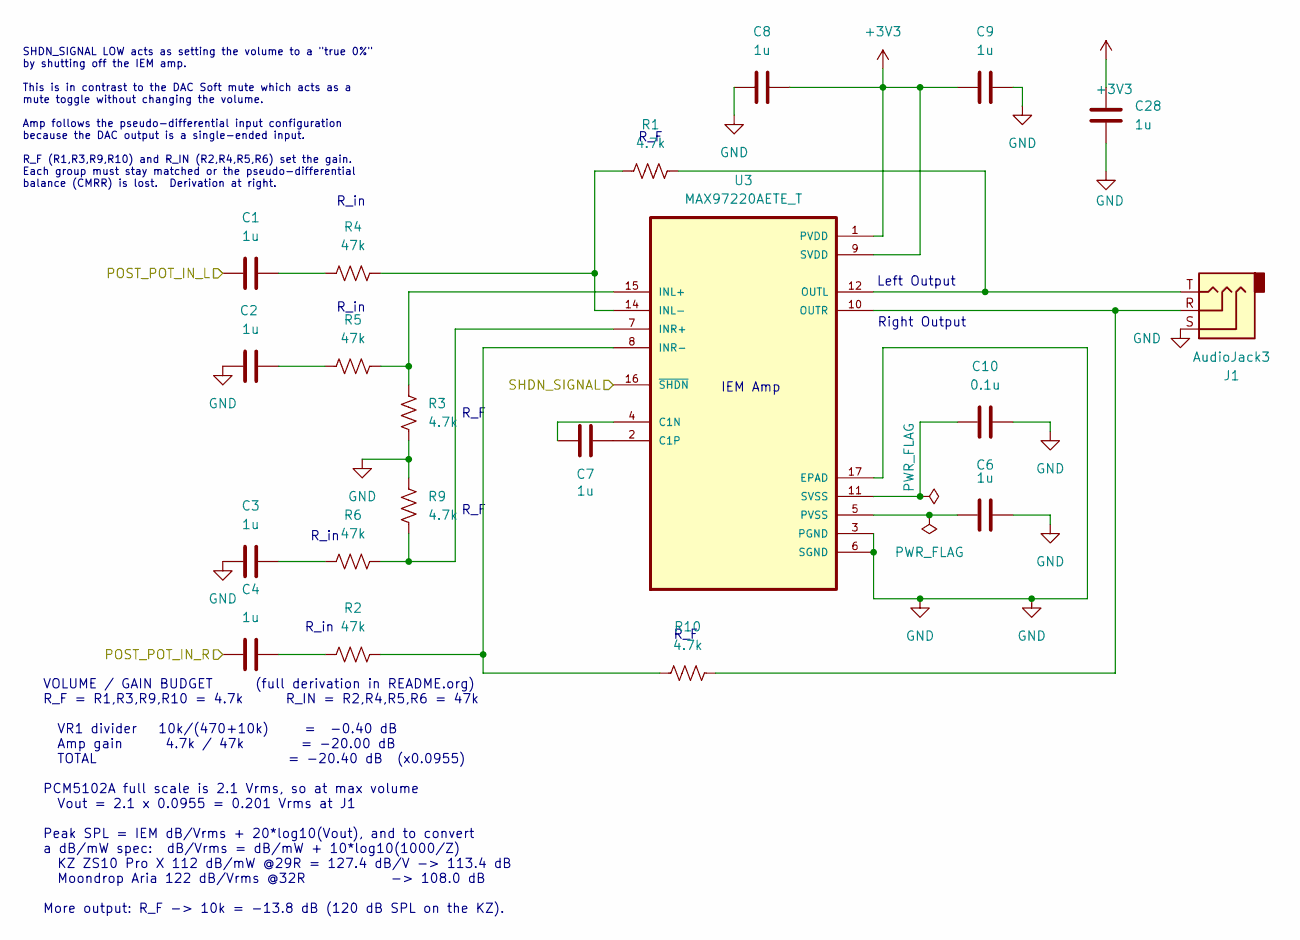
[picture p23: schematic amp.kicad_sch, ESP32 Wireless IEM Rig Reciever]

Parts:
C1, C2, C3, C4, C6, C7, C8, C9, C28: 1u; C_0805_2012Metric_Pad1.18x1.45mm_HandSolder
C10: 0.1u; C_0805_2012Metric_Pad1.18x1.45mm_HandSolder
J1: AudioJack3; Jack_3.5mm_CUI_SJ-3523-SMT_Horizontal
R1, R3, R9, R10: 4.7k; R_0805_2012Metric_Pad1.20x1.40mm_HandSolder
R2, R4, R5, R6: 47k; R_0805_2012Metric_Pad1.20x1.40mm_HandSolder
U3: MAX97220AETE_T; QFN50P300X300X80-17N

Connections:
+3V3: C8.2, C9.1, C28.1, U3.1 (PVDD), U3.9 (SVDD), U3.13 (SVDD); also elsewhere on the board
/Amp/POST_POT_IN_L: C1.1; also elsewhere on the board
/Amp/POST_POT_IN_R: C4.1; also elsewhere on the board
/Amp/SHDN_SIGNAL: U3.16 (~SHDN); also elsewhere on the board
GND: C2.1, C3.1, C6.2, C8.1, C9.2, C10.2, C28.2, J1.S, R3.2, R9.1, U3.3 (PGND), U3.6 (SGND), U3.17 (EPAD); also elsewhere on the board
unnamed: C1.2, R4.1
unnamed: C2.2, R5.1
unnamed: C3.2, R6.1
unnamed: C4.2, R2.1
unnamed: C7.2, U3.4 (C1N)
unnamed: C7.1, U3.2 (C1P)
unnamed: R3.1, R5.2, U3.15 (INL+)
unnamed: R1.1, R4.2, U3.14 (INL-)
unnamed: R6.2, R9.2, U3.7 (INR+)
unnamed: R2.2, R10.1, U3.8 (INR-)
unnamed: J1.T, R1.2, U3.12 (OUTL)
unnamed: J1.R, R10.2, U3.10 (OUTR)
unnamed: C6.1, U3.5 (PVSS)
unnamed: C10.1, U3.11 (SVSS)

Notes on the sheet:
Right Output
IEM Amp
R_in
R_F
VOLUME / GAIN BUDGET (full derivation in README.org) R_F = R1,R3,R9,R10 = 4.7k R_IN = R2,R4,R5,R6 = 47k VR1 divider 10k/(470+10k) = -0.40 dB Amp gain 4.7k / 47k = -20.00 dB TOTAL = -20.40 dB (x0.0955) PCM5102A full scale is 2.1 Vrms, so at max volume Vout = 2.1 x 0.0955 = 0.201 Vrms at J1 Peak SPL 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
Left Output
SHDN_SIGNAL LOW acts as setting the volume to a "true 0%" by shutting off the IEM amp. This is in contrast to the DAC Soft mute which acts as a mute toggle without changing the volume. Amp follows the pseudo-differential input configuration because the DAC output is a single-ended input. R_F (R1,R3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

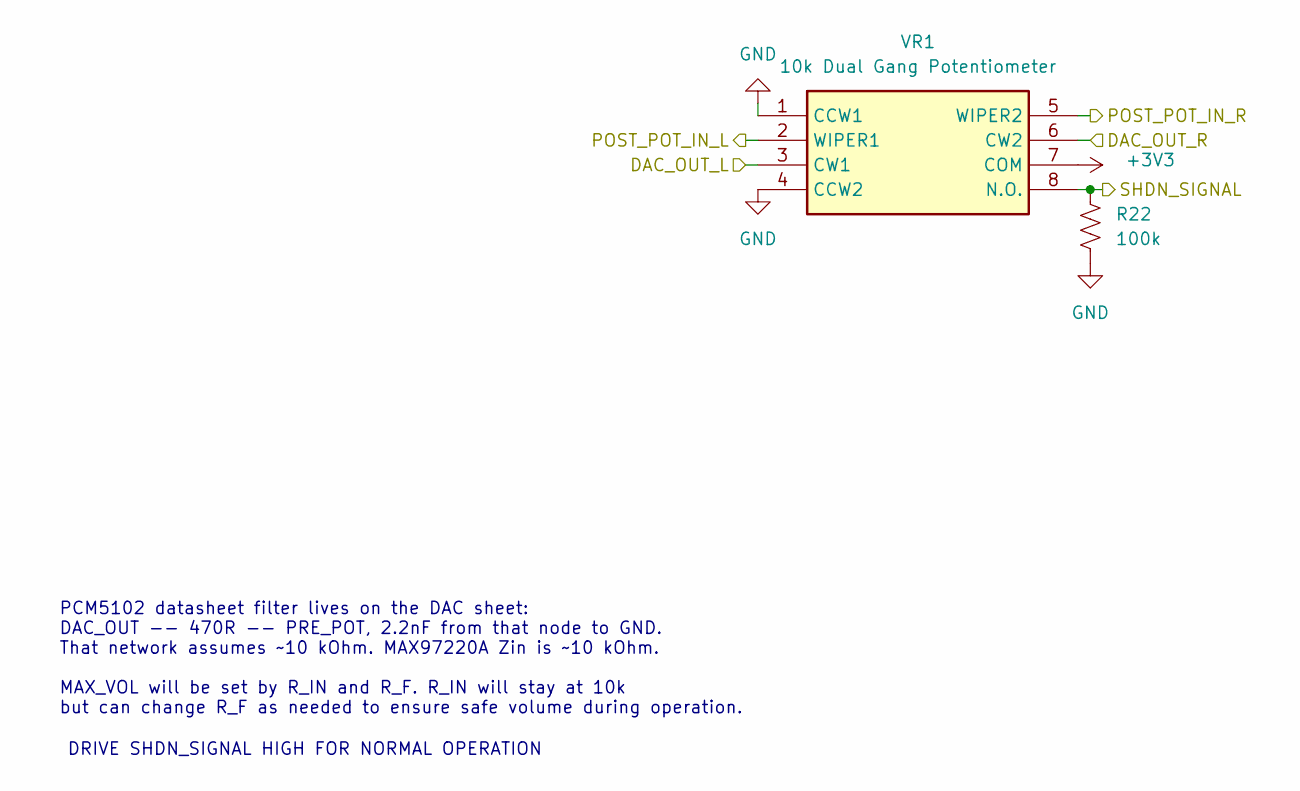
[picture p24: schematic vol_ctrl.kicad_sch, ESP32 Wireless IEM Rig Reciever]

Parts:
R22: 100k; R_0805_2012Metric_Pad1.20x1.40mm_HandSolder
VR1: 10k Dual Gang Potentiometer; PTN09S2H10120K1A; Manufacturer_Part_Number PTN09S2-H10120K1A

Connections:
+3V3: VR1.7 (COM); also elsewhere on the board
/Amp/POST_POT_IN_L: VR1.2 (WIPER1); also elsewhere on the board
/Amp/POST_POT_IN_R: VR1.5 (WIPER2); also elsewhere on the board
/Amp/SHDN_SIGNAL: R22.1, VR1.8 (N.O.); also elsewhere on the board
/DAC/DAC_OUT_L: VR1.3 (CW1); also elsewhere on the board
/DAC/DAC_OUT_R: VR1.6 (CW2); also elsewhere on the board
GND: R22.2, VR1.1 (CCW1), VR1.4 (CCW2); also elsewhere on the board

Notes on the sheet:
PCM5102 datasheet filter lives on the DAC sheet: DAC_OUT -- 470R -- PRE_POT, 2.2nF from that node to GND. That network assumes ~10 kOhm. MAX97220A Zin is ~10 kOhm. MAX_VOL will be set by R_IN and R_F. R_IN will stay at 10k but can change R_F as needed to ensure safe volume during operation.
DRIVE SHDN_SIGNAL HIGH FOR NORMAL OPERATION

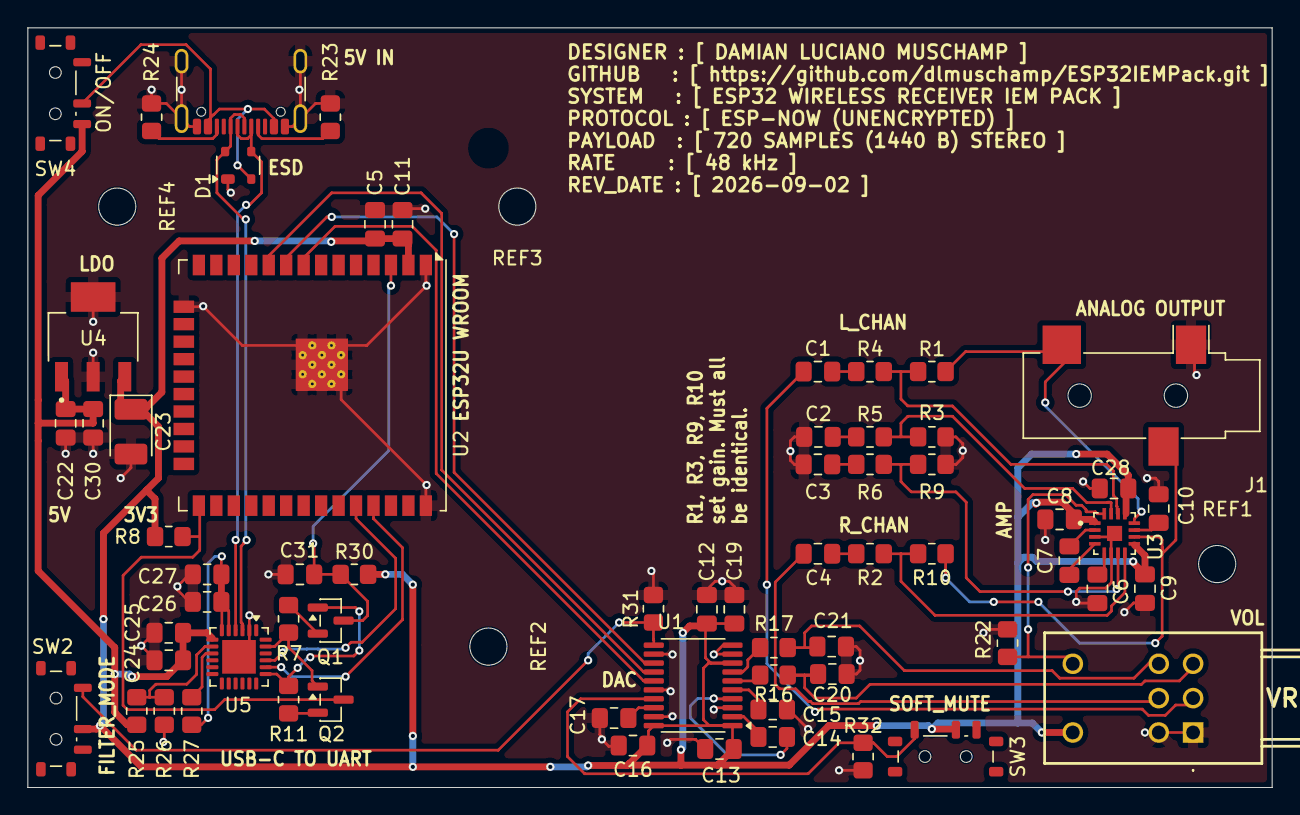
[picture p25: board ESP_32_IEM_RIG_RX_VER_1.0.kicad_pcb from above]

Board: 2 copper layers, 90.5 x 55.2 mm, 69 parts (0 on the bottom side), 49 nets.

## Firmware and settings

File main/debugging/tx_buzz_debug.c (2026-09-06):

/**
 * @file tx_buzz_debug.c
 * @brief IEM transmitter (TX pack): accepts RX pairing over ESP-NOW, then
 *        streams PCM from a PCM1808 ADC via I2S.
 *
 * Boot → idle until an RX pairs → capture on core 1 and ESP-NOW send. ESP-NOW
 * callbacks only manage peers / mode; I2S reads stay off the Wi-Fi task. When
 * the last peer drops, the pack returns to idle and stops capture.
 *
 * PCM1808 (slave) wiring note:
 *   MCLK → SCK, BCLK → BCK, WS → LRCK, DIN ← DOUT.
 * In slave mode the ADC needs 64 BCK/frame (not 32). 16-bit stereo slots force
 * BCK = 32*fs and DOUT to silence; 32-bit stereo slots give BCK = 64*fs.
 * MCLK stays at 256*fs. See TI PCM1808 datasheet §7.3.5.1.2.
 */

#include "driver/gpio.h"
#include "driver/i2s_common.h"
#include "driver/i2s_std.h"
#include "driver/i2s_types.h"
#include "esp_now.h"
#include "esp_timer.h"
#include "esp_wifi_types_generic.h"
#include "freertos/idf_additions.h"
#include "freertos/projdefs.h"
#include "freertos/queue.h"
#include "freertos/task.h"
#include "hal/i2s_types.h"
#include "portmacro.h"
#include "../rig_shared.h"
#include <stdbool.h>
#include <stdint.h>
#include <stdio.h>
#include <string.h>

#ifndef INT16_MAX
#define INT16_MAX 32767
#endif
#ifndef INT16_MIN
#define INT16_MIN (-32768)
#endif

// --- HARDWARE ---
#define BCK_PIN 33
#define LRCK_PIN 32
#define DIN_PIN 35
#define SCK_PIN 0
// Digital gain after >>16. Keep at 1 while debugging harsh/muffled (2 clips easily).
#define TX_DIGITAL_GAIN 1
// How often to log peak |sample| (pre-gain) to judge ADC level vs noise floor.
#define TX_PEAK_LOG_INTERVAL_MS 2000
// How often to print ESP-NOW send-fail totals while transmitting.
#define DROP_LOG_INTERVAL_MS 2000

// --- TIMING / BUFFERS ---
// Poll period while idling for peers or watching peer count while transmitting.
#define MODE_POLL_INTERVAL_MS 50
// Match one audio packet per DMA descriptor for low I2S path delay.
#define I2S_DMA_DESC_NUM 3
#define I2S_DMA_FRAME_NUM AUDIO_FRAMES_PER_PACKET
#define AUDIO_TASK_PRIO 12
#define AUDIO_TASK_CORE 1
// How many times to fire PAIR_SUCCESS (audio TX can starve a single ACK).
#define PAIR_ACK_REPEAT 8
// After a re-pair request, skip this many audio sends so ACKs get airtime.
// ~24 * 2.5 ms ≈ 60 ms of silence for pairing frames to land.
#define PAIR_ACK_AUDIO_SKIP 24
#define SEND_IN_FLIGHT_WAIT_US 4000
// No MAC-layer send success for this long → peer is gone (ESP-IDF: send_cb
// returns FAIL when destination does not exist / frame never ACKed at MAC).
#define TX_LINK_TIMEOUT_MS 1500
// Consecutive send_cb FAILs before we treat the link as dead (faster path).
#define TX_SEND_FAIL_STREAK_LIMIT 40

// --- MODES ---
typedef enum {
    TX_MODE_BOOTING,
    TX_MODE_IDLING,
    TX_MODE_TRANSMITTING
} tx_mode_t;

// --- GLOBALS ---
static i2s_chan_handle_t i2s_adc_chan;
static uint8_t peers_connected = 0;
static uint32_t dropped_packets = 0;
static uint8_t paired_peer_mac[ESP_NOW_ETH_ALEN] = {0};
static bool have_paired_peer = false;
// Set from pairing handler; audio task skips sends briefly so ACK can go out.
static volatile int pair_ack_audio_skip = 0;
// Pairing work must NOT run inside esp_now recv_cb (Wi-Fi task).
typedef struct {
    uint8_t mac[ESP_NOW_ETH_ALEN];
    char alias[ALIAS_BUFFER_SIZE];
} pending_pair_req_t;
static QueueHandle_t pair_req_q;

// Updated from ESP-NOW recv callback; read on the app_main state machine.
static volatile tx_mode_t cur_mode = TX_MODE_BOOTING;
static volatile bool audio_task_stop = false;
static TaskHandle_t audio_task_handle = NULL;
// Link health from send_cb (Wi-Fi task) — read on transmit state machine.
static volatile TickType_t last_send_ok_tick = 0;
static volatile uint32_t send_fail_streak = 0;
// Docs: wait for prior send_cb before the next esp_now_send to avoid CB
// disorder / NO_MEM under burst load.
static volatile bool send_in_flight = false;

// I2S delivers one 32-bit word per slot; pack down to int16 for packets.
static int32_t raw_audio_samples[AUDIO_DATA_NUM_SAMPLES];
// Keep off the audio task stack — sizeof(audio_packet_t) is 480 B @ 2.5 ms pkts.
static audio_packet_t tx_packet;

static esp_now_rate_config_t peer_rate_cfg = {
    // 12M is more robust than 24M; 480 B airtime is tiny vs 2.5 ms period.
    .rate = WIFI_PHY_RATE_12M,
    .phymode = WIFI_PHY_MODE_11G,
    .ersu = false,
    .dcm = false,
};

// --- LOG TAGS ---
static const char *INIT = "TX_INIT";
static const char *IDLE = "TX_IDLE";
static const char *TRANSMIT = "TX_TRANSMIT";
static const char *PAIR = "TX_PAIR";
static const char *CB = "TX_CB";

// --- INIT ---

/**
 * @brief I2S master RX from PCM1808 (DIN + MCLK; simplex TX pack).
 * @return ESP_OK on success, or the first failing I2S esp_err_t.
 */
static esp_err_t init_i2s_pcm1808(void) {
    i2s_chan_config_t chan_cfg =
        I2S_CHANNEL_DEFAULT_CONFIG(I2S_NUM_0, I2S_ROLE_MASTER);
    chan_cfg.dma_desc_num = I2S_DMA_DESC_NUM;
    chan_cfg.dma_frame_num = I2S_DMA_FRAME_NUM;

    i2s_std_config_t std_cfg = {
        .clk_cfg = I2S_STD_CLK_DEFAULT_CONFIG(SAMPLE_RATE),
        // 32-bit slots so BCK = 64*fs (PCM1808 rejects 16-bit / 32*fs).
        .slot_cfg = I2S_STD_PHILIPS_SLOT_DEFAULT_CONFIG(
            I2S_DATA_BIT_WIDTH_32BIT, I2S_SLOT_MODE_STEREO),
        .gpio_cfg =
            {
                .mclk = SCK_PIN,
                .bclk = BCK_PIN,
                .ws = LRCK_PIN,
                .dout = I2S_GPIO_UNUSED,
                .din = DIN_PIN,
                .invert_flags =
                    {
                        .mclk_inv = false,
                        .bclk_inv = false,
                        .ws_inv = false,
                    },
            },
    };
    // 256*fs is a valid PCM1808 SCKI ratio and divides cleanly with 64*fs BCK.
    std_cfg.clk_cfg.mclk_multiple = I2S_MCLK_MULTIPLE_256;

    esp_err_t err = i2s_new_channel(&chan_cfg, NULL, &i2s_adc_chan);
    if (err != ESP_OK) {
        ESP_LOGE(INIT, "Failed to create I2S ADC channel.");
        return err;
    }
    err = i2s_channel_init_std_mode(i2s_adc_chan, &std_cfg);
    if (err != ESP_OK) {
        ESP_LOGE(INIT, "Failed to init I2S ADC std mode.");
        return err;
    }
    err = i2s_channel_enable(i2s_adc_chan);
    if (err != ESP_OK) {
        ESP_LOGE(INIT, "Failed to enable I2S ADC channel.");
        return err;
    }

    gpio_set_drive_capability(SCK_PIN, GPIO_DRIVE_CAP_3);
    return ESP_OK;
}

// --- HELPERS ---

/** @brief Drop the active RX peer and return TX to a clean idle-ready state. */
static void clear_paired_peer(const char *reason) {
    if (have_paired_peer) {
        esp_err_t err = esp_now_del_peer(paired_peer_mac);
        if (err != ESP_OK && err != ESP_ERR_ESPNOW_NOT_FOUND) {
            ESP_LOGW(PAIR, "del_peer failed (%s): %s", reason,
                     esp_err_to_name(err));
        }
        have_paired_peer = false;
        memset(paired_peer_mac, 0, sizeof(paired_peer_mac));
    }
    peers_connected = 0;
    ESP_LOGW(PAIR, "Cleared RX peer (%s); returning to idle.", reason);
    cur_mode = TX_MODE_IDLING;
}

/**
 * @brief Add RX peer, ACK at default rate, then set 11g/24M. Task context only.
 */
static void handle_connect_new_peer(esp_now_peer_info_t *new_peer) {
    if (!new_peer) {
        ESP_LOGW(PAIR, "NULL peer info; skipping.");
        return;
    }

    esp_err_t add_status = esp_now_add_peer(new_peer);
    bool peer_ok = false;

    if (add_status == ESP_OK) {
        ESP_LOGI(PAIR, "RX paired successfully.");
        peers_connected++;
        peer_ok = true;
    } else if (add_status == ESP_ERR_ESPNOW_EXIST) {
        ESP_LOGI(PAIR, "RX already paired; re-ACKing.");
        if (peers_connected == 0) {
            peers_connected = 1;
        }
        peer_ok = true;
    } else {
        ESP_LOGW(PAIR, "Failed to add RX as peer: %s",
                 esp_err_to_name(add_status));
        uint8_t fail_byte = (uint8_t)PAIR_FAIL;
        esp_now_send(new_peer->peer_addr, &fail_byte, PAIR_ACK_LEN);
        return;
    }

    memcpy(paired_peer_mac, new_peer->peer_addr, ESP_NOW_ETH_ALEN);
    have_paired_peer = true;
    last_send_ok_tick = xTaskGetTickCount();
    send_fail_streak = 0;

    // ACK before rate_config — default PHY is more reliable for pairing.
    // Docs: esp_now_set_peer_rate_config must run AFTER esp_now_add_peer.
    uint8_t succ_byte = (uint8_t)PAIR_SUCCESS;
    int ack_ok = 0;
    for (int i = 0; i < PAIR_ACK_REPEAT; i++) {
        if (esp_now_send(new_peer->peer_addr, &succ_byte, PAIR_ACK_LEN) ==
            ESP_OK) {
            ack_ok++;
        }
        vTaskDelay(pdMS_TO_TICKS(5));
    }
    pair_ack_audio_skip = PAIR_ACK_AUDIO_SKIP;
    ESP_LOGI(PAIR, "Sent PAIR_SUCCESS ACK x%d (%d ok).", PAIR_ACK_REPEAT,
             ack_ok);

    esp_err_t rate_status =
        esp_now_set_peer_rate_config(new_peer->peer_addr, &peer_rate_cfg);
    if (rate_status != ESP_OK) {
        ESP_LOGW(PAIR, "Peer OK but rate config failed: %s",
                 esp_err_to_name(rate_status));
    }

    if (peers_connected > 0) {
        cur_mode = TX_MODE_TRANSMITTING;
    }
}

/** @brief Drain pairing queue — safe place to call esp_now_send/add_peer. */
static void process_pending_pair_requests(void) {
    if (!pair_req_q) {
        return;
    }
    pending_pair_req_t req;
    while (xQueueReceive(pair_req_q, &req, 0) == pdTRUE) {
        if (strncmp(req.alias, BASE_RX_ALIAS, strlen(BASE_RX_ALIAS)) != 0) {
            ESP_LOGI(PAIR, "Ignoring non-RX alias '%s'.", req.alias);
            continue;
        }
        ESP_LOGI(PAIR,
                 "Handling pairing from %02X:%02X:%02X:%02X:%02X:%02X (%s).",
                 req.mac[0], req.mac[1], req.mac[2], req.mac[3], req.mac[4],
                 req.mac[5], req.alias);

        esp_now_peer_info_t new_peer = {
            .channel = DEFAULT_CHANNEL,
            .ifidx = WIFI_IF_STA,
            .encrypt = false,
        };
        memcpy(new_peer.peer_addr, req.mac, ESP_NOW_ETH_ALEN);
        handle_connect_new_peer(&new_peer);
    }
}

// --- TASKS ---

/**
 * @brief Scale int16 sample by TX_DIGITAL_GAIN and clamp to int16 range.
 */
static inline int16_t apply_tx_gain(int32_t sample_i16) {
    int32_t gained = sample_i16 * TX_DIGITAL_GAIN;
    if (gained > INT16_MAX) {
        return INT16_MAX;
    }
    if (gained < INT16_MIN) {
        return INT16_MIN;
    }
    return (int16_t)gained;
}

/**
 * @brief Core-1 producer: I2S ADC → pack int16 → ESP-NOW. Exits on stop flag.
 *        Always sends while transmitting (silence = zeros, not a skipped packet).
 */
static void audio_capture_task(void *pvParameters) {
    (void)pvParameters;
    TickType_t last_drop_log = xTaskGetTickCount();
    uint32_t last_logged_drops = 0;
    TickType_t last_peak_log = xTaskGetTickCount();
    int32_t peak_abs_pre = 0;

    while (!audio_task_stop) {
        size_t bytes_read = 0;
        esp_err_t i2s_read_status = i2s_channel_read(
            i2s_adc_chan, raw_audio_samples, sizeof(raw_audio_samples),
            &bytes_read, portMAX_DELAY);

        if (i2s_read_status != ESP_OK || bytes_read == 0) {
            ESP_LOGW(TRANSMIT, "I2S ADC read failed.");
            continue;
        }
        if (audio_task_stop) {
            break;
        }

        size_t samples_read = bytes_read / sizeof(raw_audio_samples[0]);
        if (bytes_read != sizeof(raw_audio_samples)) {
            ESP_LOGW(TRANSMIT, "Partial I2S read: %u / %u bytes.",
                     (unsigned)bytes_read, (unsigned)sizeof(raw_audio_samples));
        }
        if (samples_read > AUDIO_DATA_NUM_SAMPLES) {
            samples_read = AUDIO_DATA_NUM_SAMPLES;
        }
        if (samples_read < AUDIO_DATA_NUM_SAMPLES) {
            memset(&tx_packet.audio_data[samples_read], 0,
                   (AUDIO_DATA_NUM_SAMPLES - samples_read) * sizeof(int16_t));
        }

        for (size_t i = 0; i < samples_read; i++) {
            int32_t sample = raw_audio_samples[i] >> 16;
            int32_t a = (sample < 0) ? -sample : sample;
            if (a > peak_abs_pre) {
                peak_abs_pre = a;
            }
            tx_packet.audio_data[i] = apply_tx_gain(sample);
        }

        if (pair_ack_audio_skip > 0) {
            pair_ack_audio_skip--;
            continue;
        }

        // Pace sends to send_cb (ESP-IDF recommendation). µs deadline — with
        // CONFIG_FREERTOS_HZ=100, pdMS_TO_TICKS(1..9) is 0 and a 10 ms tick is
        // already four packet periods.
        const int64_t wait_deadline_us =
            esp_timer_get_time() + SEND_IN_FLIGHT_WAIT_US;
        while (send_in_flight && esp_timer_get_time() < wait_deadline_us) {
            taskYIELD();
        }

        send_in_flight = true;
        esp_err_t send_err =
            esp_now_send(have_paired_peer ? paired_peer_mac : NULL,
                         (uint8_t *)&tx_packet, sizeof(tx_packet));
        if (send_err != ESP_OK) {
            send_in_flight = false;
            dropped_packets++;
            // Docs: ESP_ERR_ESPNOW_NO_MEM → delay before the next send.
            if (send_err == ESP_ERR_ESPNOW_NO_MEM) {
                vTaskDelay(pdMS_TO_TICKS(1));
            }
        }

        TickType_t now = xTaskGetTickCount();
        if ((now - last_peak_log) >= pdMS_TO_TICKS(TX_PEAK_LOG_INTERVAL_MS)) {
            ESP_LOGI(TRANSMIT,
                     "ADC peak|pre-gain|=%ld / 32767 (digital_gain=%d)",
                     (long)peak_abs_pre, TX_DIGITAL_GAIN);
            peak_abs_pre = 0;
            last_peak_log = now;
        }
        if ((now - last_drop_log) >= pdMS_TO_TICKS(DROP_LOG_INTERVAL_MS)) {
            uint32_t delta = dropped_packets - last_logged_drops;
            if (delta > 0) {
                ESP_LOGI(TRANSMIT,
                         "ESP-NOW send fails: +%lu in last %d ms (total %lu).",
                         (unsigned long)delta, DROP_LOG_INTERVAL_MS,
                         (unsigned long)dropped_packets);
            }
            last_logged_drops = dropped_packets;
            last_drop_log = now;
        }
    }

    audio_task_handle = NULL;
    vTaskDelete(NULL);
}

/**
 * @brief Wait until cur_mode leaves IDLING (an RX paired).
 */
static void run_idling_state(void) {
    ESP_LOGI(IDLE, "Waiting for RX peers to connect.");
    while (cur_mode == TX_MODE_IDLING) {
        process_pending_pair_requests();
        vTaskDelay(pdMS_TO_TICKS(MODE_POLL_INTERVAL_MS));
    }
}

/**
 * @brief Run capture on core 1; return to idle when peer count hits zero
 *        or MAC-layer send health says the RX is gone.
 */
static void run_transmitting_state(void) {
    audio_task_stop = false;
    last_send_ok_tick = xTaskGetTickCount();
    send_fail_streak = 0;

    BaseType_t created = xTaskCreatePinnedToCore(
        audio_capture_task, "AudioCapture", AUDIO_TASK_STACK, NULL,
        AUDIO_TASK_PRIO, &audio_task_handle, AUDIO_TASK_CORE);
    if (created != pdPASS) {
        ESP_LOGE(TRANSMIT, "Failed to create audio capture task.");
        clear_paired_peer("audio task create failed");
        return;
    }

    while (cur_mode == TX_MODE_TRANSMITTING) {
        process_pending_pair_requests();
        vTaskDelay(pdMS_TO_TICKS(MODE_POLL_INTERVAL_MS));
        if (peers_connected == 0) {
            cur_mode = TX_MODE_IDLING;
            break;
        }
        // If the capture task died (stack/overflow/abort), drop the peer so
        // RX can re-pair and we can start a fresh transmit session.
        if (audio_task_handle == NULL) {
            clear_paired_peer("audio task died");
            break;
        }

        // Link loss: ESP-IDF send_cb FAIL means MAC did not confirm delivery
        // (peer gone / channel mismatch / air loss). Drop peer so we idle and
        // can accept a clean re-pair instead of blasting into the void.
        TickType_t now = xTaskGetTickCount();
        bool timed_out = (now - last_send_ok_tick) >
                         pdMS_TO_TICKS(TX_LINK_TIMEOUT_MS);
        bool fail_streak = send_fail_streak >= TX_SEND_FAIL_STREAK_LIMIT;
        if (timed_out || fail_streak) {
            ESP_LOGW(TRANSMIT,
                     "RX link lost (timeout=%d streak=%lu); clearing peer.",
                     timed_out ? 1 : 0, (unsigned long)send_fail_streak);
            clear_paired_peer(timed_out ? "send timeout" : "send fail streak");
            break;
        }
    }

    audio_task_stop = true;
    while (audio_task_handle != NULL) {
        vTaskDelay(pdMS_TO_TICKS(10));
    }
}

// --- CALLBACKS ---

/**
 * @brief ESP-NOW receive: copy pairing requests to a queue (no esp_now_send here).
 */
static void recv_cb(const esp_now_recv_info_t *esp_now_info,
                    const uint8_t *pair_req, int data_size) {
    if (!esp_now_info || !pair_req || !pair_req_q) {
        return;
    }

    if (data_size != (int)sizeof(pairing_req_packet_t)) {
        ESP_LOGD(CB, "Ignoring non-pairing packet (size %d).", data_size);
        return;
    }

    pending_pair_req_t req = {0};
    memcpy(req.mac, esp_now_info->src_addr, ESP_NOW_ETH_ALEN);
    const pairing_req_packet_t *pac = (const pairing_req_packet_t *)pair_req;
    memcpy(req.alias, pac->alias, ALIAS_BUFFER_SIZE);
    req.alias[ALIAS_BUFFER_SIZE - 1] = '\0';

    if (xQueueSend(pair_req_q, &req, 0) != pdTRUE) {
        ESP_LOGW(PAIR, "Pairing queue full; dropping request.");
    } else {
        ESP_LOGI(PAIR, "Queued pairing request (%d bytes).", data_size);
    }
}

/**
 * @brief ESP-NOW send status. Air failures counted; used for TX link-loss.
 *
 * Evidence (ESP-IDF ESP-NOW docs): send_cb returns ESP_NOW_SEND_SUCCESS only if
 * the data was received successfully on the MAC layer; otherwise FAIL (peer
 * missing, channel mismatch, air loss, etc.).
 */
static void send_cb(const esp_now_send_info_t *info,
                    esp_now_send_status_t status) {
    if (!info) {
        ESP_LOGW(CB, "NULL send_info in send_cb.");
        return;
    }
    if (status == ESP_NOW_SEND_SUCCESS) {
        last_send_ok_tick = xTaskGetTickCount();
        send_fail_streak = 0;
        send_in_flight = false;
        return;
    }
    dropped_packets++;
    send_fail_streak++;
    send_in_flight = false;
}

void app_main(void) {
    _Static_assert(sizeof(audio_packet_t) <= ESP_NOW_MAX_DATA_LEN_V2,
                   "audio_packet_t exceeds ESP-NOW v2 max");

    while (1) {
        switch (cur_mode) {
        case TX_MODE_BOOTING: {
            ESP_ERROR_CHECK(init_nvs());
            ESP_ERROR_CHECK(init_wifi());
            ESP_ERROR_CHECK(init_espnow(recv_cb, send_cb));
            verify_espnow_ver();
            // Re-lock channel after esp_now_init (IDF can forget it).
            ESP_ERROR_CHECK(
                esp_wifi_set_channel(DEFAULT_CHANNEL, SECONDARY_CHANNEL));
            ESP_ERROR_CHECK(esp_wifi_set_ps(WIFI_PS_NONE));

            pair_req_q = xQueueCreate(4, sizeof(pending_pair_req_t));
            if (!pair_req_q) {
                ESP_LOGE(INIT, "Failed to create pairing queue.");
                abort();
            }

            // Enter IDLING before slow I2S bring-up so mid-init pairs are kept.
            cur_mode = TX_MODE_IDLING;
            ESP_ERROR_CHECK(init_i2s_pcm1808());
            break;
        }

        case TX_MODE_IDLING:
            run_idling_state();
            break;

        case TX_MODE_TRANSMITTING:
            run_transmitting_state();
            break;

        default:
            ESP_LOGW(INIT, "Unknown mode; rebooting state machine.");
            cur_mode = TX_MODE_BOOTING;
            break;
        }
    }
}

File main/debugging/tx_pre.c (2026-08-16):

#include "driver/gpio.h"
#include "driver/i2s_common.h"
#include "driver/i2s_std.h"
#include "driver/i2s_types.h"
#include "esp_err.h"
#include "esp_event.h"
#include "esp_log.h"
#include "esp_now.h"
#include "esp_wifi.h"
#include "esp_wifi_types_generic.h"
#include "freertos/FreeRTOS.h"
#include "freertos/idf_additions.h"
#include "freertos/task.h"
#include "hal/i2s_types.h"
#include "nvs.h"
#include "nvs_flash.h"
#include "portmacro.h"
#include "rig_shared.h"
#include <stdint.h>
#include <stdio.h>
#include <string.h>
#include <sys/types.h>

// --- MACROS ---

/** ESP_TX (MASTER) to PCM1808 (SLAVE)
 *  MCLK ---> SCK  (System Clock)
 *  BCLK ---> BCK  (Bit Clock)
 *  WS   ---> LRCK (Word Select [Left or Right])
 *  DIN <---- DOUT (Microphone Digital Out)
 *
 *  SNAPSHOT: pre-fix copy of tx.c (16-bit I2S slots). Kept for review.
 *  Active firmware is tx.c — see comments there for the PCM1808 BCK fix.
 *  app_main renamed to deprecated_app_main so this file cannot collide if
 *  accidentally added to the build.
 **/

// DEBUG LED PIN
#define INTERNAL_LED_PIN 2

#define I2S_BCK_PIN 33
#define I2S_LRCK_PIN 32
#define I2S_DIN_PIN 35
#define I2S_SCK_PIN 0 // 0

// --- GLOBALS ---
static const char *TAG = "TX_NODE";
i2s_chan_handle_t i2s_adc_chan;
uint8_t peers_connected = 0x00;
uint32_t dropped_packets = 0;

// --- THE HANDSHAKE CALLBACK ---
void on_esp_now_recv(const esp_now_recv_info_t *esp_now_info,
                     const uint8_t *data, int data_len) {

  if (data_len != sizeof(discovery_packet_t)) {
    ESP_LOGE(TAG, "Received data size is different than "
             "discovery_packet_t. Ignoring.");
    return;
  }

  discovery_packet_t *cur_pac = (discovery_packet_t *)data;
  if (strncmp(cur_pac->alias, BASE_RX_ALIAS, strlen(BASE_RX_ALIAS)) != 0) {
    ESP_LOGI(TAG,
             "Current packet does not contain a valid RX alias. Ignoring");
    return;
  }

  esp_now_peer_info_t new_peer = {
    .channel = DEFAULT_CHANNEL, .ifidx = WIFI_IF_STA, .encrypt = false};

  memcpy(new_peer.peer_addr, esp_now_info->src_addr, ESP_NOW_ETH_ALEN);

  esp_err_t add_status = esp_now_add_peer(&new_peer);

  if (add_status == ESP_OK) {
    ESP_LOGI(TAG, "RX paired successfully.");
    peers_connected |= (~peers_connected) & (peers_connected + 1);
  } else if (add_status == ESP_ERR_ESPNOW_EXIST) {
    ESP_LOGI(TAG, "RX already paired. Ignoring.");
  } else {
    ESP_LOGE(TAG, "Failed to add RX as peer.");
  }
}

// --- HARDWARE INIT ---
void init_nvs(void) {
  esp_err_t nvs_status = nvs_flash_init();

  if (nvs_status == ESP_ERR_NVS_NO_FREE_PAGES ||
    nvs_status == ESP_ERR_NVS_NEW_VERSION_FOUND) {
    ESP_LOGW(TAG, "Failed to initialize NVS flash. Erasing and retrying.");
    ESP_ERROR_CHECK(nvs_flash_erase());
    ESP_ERROR_CHECK(nvs_flash_init());
  }

  ESP_ERROR_CHECK(nvs_status);
  ESP_LOGI(TAG, "NVS initialized successfully.");
}

// not doing long range mode
void init_wifi(void) {
  ESP_ERROR_CHECK(esp_netif_init());
  ESP_ERROR_CHECK(esp_event_loop_create_default());
  wifi_init_config_t wifi_cfg = WIFI_INIT_CONFIG_DEFAULT();
  ESP_ERROR_CHECK(esp_wifi_init(&wifi_cfg));
  ESP_ERROR_CHECK(esp_wifi_set_storage(WIFI_STORAGE_RAM));
  ESP_ERROR_CHECK(esp_wifi_set_mode(WIFI_MODE_STA));
  ESP_ERROR_CHECK(esp_wifi_start());
  // TODO: replace rig shared with these wifi values
  ESP_ERROR_CHECK(esp_wifi_set_channel(1, WIFI_SECOND_CHAN_NONE));
}

void transmit_cb(const esp_now_send_info_t *tx_info,
                 esp_now_send_status_t status) {

  if (!tx_info) {
    ESP_LOGE(TAG, "TX info passed a null pointer.");
    return;
  }

  if (status != ESP_NOW_SEND_SUCCESS) {
    dropped_packets++;
  }
}

// decomposing this functoin
void init_espnow(void) {
  ESP_ERROR_CHECK(esp_now_init());
  ESP_ERROR_CHECK(esp_now_register_recv_cb(on_esp_now_recv));
  ESP_ERROR_CHECK(esp_now_register_send_cb(transmit_cb));
}

void init_i2s_microphone(void) {
  i2s_chan_config_t i2s_chan_cfg =
    I2S_CHANNEL_DEFAULT_CONFIG(I2S_NUM_0, I2S_ROLE_MASTER);

  i2s_std_config_t i2s_std_cfg = {
    .clk_cfg = I2S_STD_CLK_DEFAULT_CONFIG(SAMPLE_RATE),
    .slot_cfg = I2S_STD_PHILIPS_SLOT_DEFAULT_CONFIG(I2S_DATA_BIT_WIDTH_16BIT, I2S_SLOT_MODE_STEREO),

    .gpio_cfg = {.bclk = I2S_BCK_PIN,
      .ws = I2S_LRCK_PIN,
      .din = I2S_DIN_PIN,
      .mclk = I2S_SCK_PIN,
      .dout = I2S_GPIO_UNUSED
    },
  };


  i2s_std_cfg.clk_cfg.mclk_multiple = I2S_MCLK_MULTIPLE_256;

  ESP_ERROR_CHECK(i2s_new_channel(&i2s_chan_cfg, NULL, &i2s_adc_chan));
  ESP_ERROR_CHECK(i2s_channel_init_std_mode(i2s_adc_chan, &i2s_std_cfg));
  ESP_ERROR_CHECK(i2s_channel_enable(i2s_adc_chan));
  gpio_set_drive_capability(0, GPIO_DRIVE_CAP_3);
}

// --- MAIN THREAD ---
void deprecated_app_main(void) {
  printf("Booting TX Node...\n");

  init_nvs();
  init_wifi();
  init_espnow();
  init_i2s_microphone();

  printf("Waiting for RX bodypacks to ping...\n");

  // remove this after testing.
  gpio_reset_pin(INTERNAL_LED_PIN);
  gpio_set_direction(INTERNAL_LED_PIN, GPIO_MODE_OUTPUT);

  // Create your audio_packet_t payload struct variable and initialize
  // the packet_id to 0.
  audio_packet_t audio_samples = {.packet_id = 0};
  size_t audio_data_size = sizeof(audio_samples.audio_data);

  while (1) {
    size_t bytes_read = 0;
    if (1) { // TODO: replace with peers_connected when done testing
      // Read from i2s_adc_chan to audio_data array.
      // Use portMAX_DELAY so the task blocks until the buffer is 100%
      // full.
      esp_err_t i2s_read_status =
        i2s_channel_read(i2s_adc_chan, audio_samples.audio_data,
                         audio_data_size, &bytes_read, portMAX_DELAY);

      if (i2s_read_status != ESP_OK || bytes_read == 0) {
        ESP_LOGW(TAG, "Failed to read bytes from I2S ADC Channel.");
        // TODO: Remove after testing 
        vTaskDelay(pdMS_TO_TICKS(1000));
        continue;
      }

      // TODO: remove this after testing

      int loop_counter = 0;

      if (loop_counter++ % 20 == 0) {
        int16_t sample_val = *((int16_t *)&audio_samples.audio_data[0]);
        printf("Mic level: %d\n", sample_val);


      }
      // Send once full and increment packet id
      // TODO: esp_now_send(NULL, audio_samples_address,
      // audio_samples_size);
      audio_samples.packet_id++;

      vTaskDelay(pdMS_TO_TICKS(100)); // Idling

    } else {
      vTaskDelay(pdMS_TO_TICKS(100)); // Idling
    }
  }
}

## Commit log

2026-08-01 Working Square Wave 440hz generator
2026-08-02 Fixed muted DAC audio by swapping .slot to use philips configuration instead of MSB.
2026-08-04 WIP RX Schematics.
    [ESP32IEMCAD.kicad_pcb, ESP32IEMCAD.kicad_sch, MAX97220AETE_T.step]
2026-08-05 First finished schematic for the IEM_RX. Also imported custom symbols.
    [EDI2CAP.CFG, ESP32IEMCAD.kicad_sch, LM3940IMPX-3.3_NOPB.step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]
2026-08-05 Resolved ERC errors.
    [ESP32IEMCAD.kicad_pcb, ESP32IEMCAD.kicad_sch, ESP32_IEM_RX_v0.0.1.kicad_sch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]
2026-08-06 Swapped misc .clangd settings to transition from VSCode on Win11 back to nvim on arch.
    Swapped from win11 dev environment to arch while laptop is getting
    repaired and needed to make misc changes to get it working on a linux
    environment. Also includes a get_idf command to prep idf.py for flashing
    to the esp via usb.
    [EDI2CAP.CFG, ESP32IEMCAD.kicad_pcb, ESP32IEMCAD.kicad_sch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]
2026-08-09 RX Ver 1.0.0 Schematics
    Schematic design complete for RX. Beginning PCB layout design.
    [ESP32IEMCAD.kicad_pcb, ESP32IEMCAD.kicad_sch, amp.kicad_sch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]
2026-08-09 Sync Latest Changes from WSL.
    [EDI2CAP.CFG, ESP32IEMCAD.kicad_sch, PTN09S2-H10120K1A.SchLib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]
2026-08-09 RX Version 1.0.0 Schematic and PDF.
    [.kicad_sch, .kicad_sch.kicad_sch, ESP32IEMCAD.kicad_pcb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]
2026-08-16 Fix PCM1808 silence by using 32-bit I2S slots.
    16-bit stereo forced BCK to 32*fs, which the ADC rejects and zeros DOUT; keep the pre-fix tx as tx_pre.c for review.
    [tx_pre.c]
2026-08-16 Rename tx_pre app_main to avoid symbol collisions.
    Keep the pre-fix snapshot as reference-only so it cannot clash with tx.c if included in a build.
    [tx_pre.c]
2026-08-19 fixed logging and error mismatches
    [tx.c]
2026-08-20 rx_v1: harden RX pack for pairing, playback, and ~10 ms streaming
    Refactor main/rx.c with broadcast peer setup, link-loss recovery, low-latency
    I2S DMA, and shared ESP-NOW v2 audio sizing so RX is ready for bring-up testing.
2026-08-21 working_audio_v1: snapshot of last known-audio TX/RX state
    Freeze the post-bring-up tree (720-sample packets, PS_NONE, unicast
    re-pair, TX ACK retries) that had audible streaming with near-zero
    jitter drops, before further pairing/reconnect hardening.
    [tx.c]
2026-08-21 fix pairing/reconnect: soft RX rejoin, TX link-loss, paced sends
    RX re-enters playback when remembered TX audio resumes while pairing
    (ACK can be starved by audio). TX drops the peer on MAC send-fail
    streak/timeout so it can idle and re-pair cleanly. Pace audio sends on
    send_cb per ESP-IDF guidance; use 12M PHY for crowded 2.4 GHz. Temporary
    RX_DBG logs live behind RX_TEMP_DEBUG_ENABLE.
    [tx.c]
2026-08-22 docs+test: archive sound-profile isolation; CER bench notes; KiCad guide
    Move tone/peak diagnostic firmware under main/testing/ so shipping
    tx.c/rx.c stay pure. Document 2026-08-21 findings (digital HF OK,
    analog/breadboard LPF+buzz) and KiCad notes for PCM5102 line-out→pot.
    [sound_profile_tones.h, tx_buzz_debug.c, tx_tone_bypass.c]
2026-08-22 docs: note 0805 passives for hand assembly in KiCad guide
2026-08-23 Reorganize KiCad into RX_SKETCHES and TX_SKETCHES.
    Keep the recovered RX 1.0.0 working copy in one place and drop the duplicate Design, Projects, and recovery folders.
    [.kicad_sch, .kicad_sch.kicad_sch, ESP32IEMCAD.kicad_pcb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]
2026-08-23 Rewrite README for the KiCad RX transfer and first-board pitfalls.
    Drop the TFT / TP4056 / LiPo story for this revision: no display,
    TX and RX each use a 10,000 mAh USB-C power bank, and the 32U needs
    a U.FL pigtail antenna. Document the firmware I2S map, sheet order,
    and the KiCad mistakes that already showed up on this schematic.
2026-08-23 Replace README.md with Org notes that match the firmware.
    Document C + FreeRTOS + ESP-IDF with no Arduino or HAL, mark tx.c
    as done for this version, and treat the sniffer only as a possible
    later extension. Say plainly this is a first self-guided embedded
    project (first C, ESP32, spec sheets, and KiCad).
2026-08-23 docs: blend bench README with KiCad RX transfer notes
    Merge the CER / firmware map from main with PR #2 hardware scope,
    I2S map, antenna, hand-assembly, and common KiCad mistakes. Mark
    datasheet schematic fixes as still pending in PR #2.
2026-08-23 chore: clean tree — drop IDE/build junk, consolidate debugging/
    Untrack .vs/.vscode/build artifacts and editor crumbs, remove sniffer,
    and move isolation/archive sources under main/debugging/ so shipping
    firmware stays at the top of main/.
    [app_update_err_codes.csv, bootloader_support_err_codes.csv, efuse_err_codes.csv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]
2026-08-30 RX v1: complete PCB layout, retune analog chain, fix ESD clamp placement
    Brings the RX schematic and board up to a fabricable state. DRC is clean:
    zero unconnected items, zero schematic-parity issues. The 16 remaining
    violations are footprint-inherent and documented rather than worked around
    (ESP32-WROOM thermal via array drilled 0.2 mm against a 0.3 mm rule, and
    USB-C NPTH-to-pad spacing from the vendor land pattern).
    Analog:
    - Gain network populated at RF 4.7k / RIN 47k (-20 dB) rather than DNP 10k.
    Tames the PCM5102's 2.1 Vrms into sensitive IEMs, gives the 10k pot a
    4.7x loading ratio instead of 1:1, and lifts the coupling corner clear of
    the audible band.
    - Coupling caps C1-C4 ra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
    [ESP_32_IEM_RIG_RX_VER_1.0.kicad_pcb, ESP_32_IEM_RIG_RX_VER_1.0.kicad_sch, amp.kicad_sch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]
2026-08-30 RX v1: map JLCPCB parts, fix LM3940 bulk cap, add production export
    Retune the LM3940 input divider to 22k/47k and swap C23 to an EIA-3528
    tantalum so the regulator meets its minimum ESR and stays stable.
    Every SMT part now carries an LCSC number in the plugin's project.db, with
    the ESP32 module and the mechanical/reference parts excluded from assembly
    so the order stays on Economic pricing. Includes the generated Gerbers,
    BOM, and CPL, plus the clean DRC/ERC reports.
    [BOM-ESP_32_IEM_RIG_RX_VER_1.0.csv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]
2026-09-01 FINISHED_RX_V1_Schematics!
    Finished V1 of RX PCBs!
    [ESP_32_IEM_RIG_RX_VER_1.0.kicad_pcb, RX_BOM_jlcpcb.xlsx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]
2026-09-01 TX_Schematic Draft
    First draft of the tx schematic. Pre-pcb commit. Reuses the same power
    management as the rx schematic. Uses an almost identical esp layout with
    minor changes. ADC is fully routed to TRS jack.
    [ESP_32_IEM_RIG_TX_VER_1.0.kicad_pcb, ESP_32_IEM_RIG_TX_VER_1.0.kicad_sch, PCM1808PWG4.step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]
2026-09-03 Ship RX+TX v1 boards: routed PCBs, JLCPCB exports, README for order spin.
    Freeze electrical intent for fab (Gerbers/BOM/CPL), document firmware design philosophy and summer timeline, and drop stale ERC/DRC/fab clutter.
    [BOM-ESP_32_IEM_RIG_TX_VER_1.0.csv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]
2026-09-05 Refresh TX/RX silk artwork and regenerate JLCPCB gerbers.
    Cosmetic pass: silkscreen, QR codes, font, and screw hole moves — BOM/CPL unchanged.
    [ESP_32_IEM_RIG_RX_VER_1.0-CuBottom.gbr, ESP_32_IEM_RIG_RX_VER_1.0-CuTop.gbr, ESP_32_IEM_RIG_RX_VER_1.0-EdgeCuts.gbr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]
2026-09-06 Cut TX→RX path toward ~10 ms with 2.5 ms packets.
    Shrink audio packets to 240 samples, drop RX prebuffer to 2, tighten DMA
    depth, and pace ESP-NOW sends on a µs deadline so FREERTOS_HZ=100 does not
    stall the shorter packet period.
    [sound_profile_tones.h, tx.c, tx_buzz_debug.c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]
